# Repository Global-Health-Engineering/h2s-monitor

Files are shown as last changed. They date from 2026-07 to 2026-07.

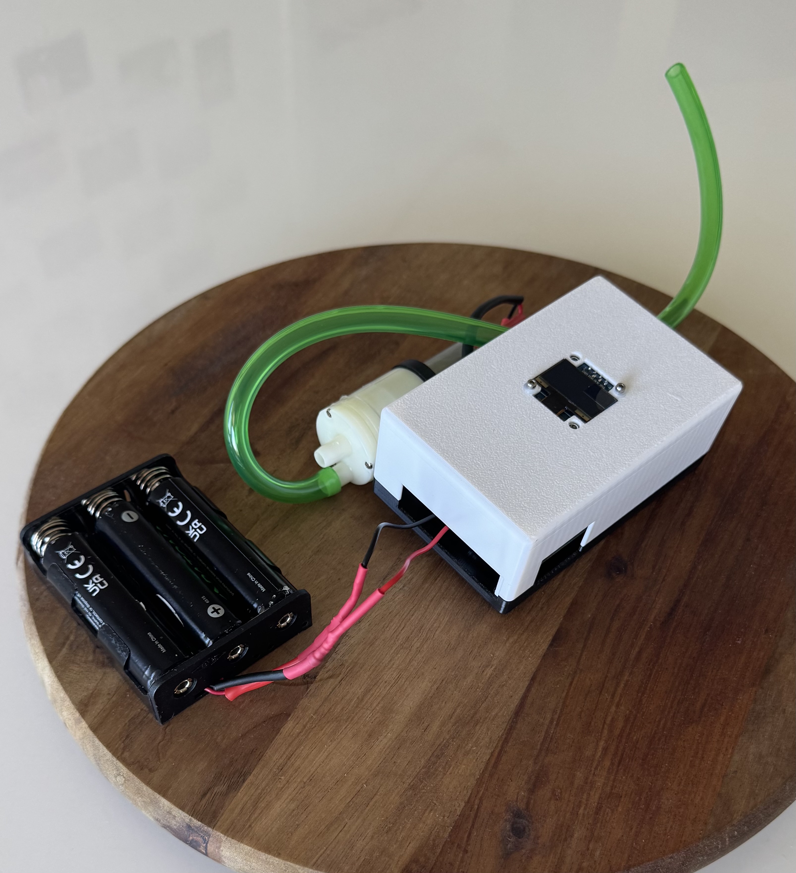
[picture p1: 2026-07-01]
media/photo/device_closed.jpeg

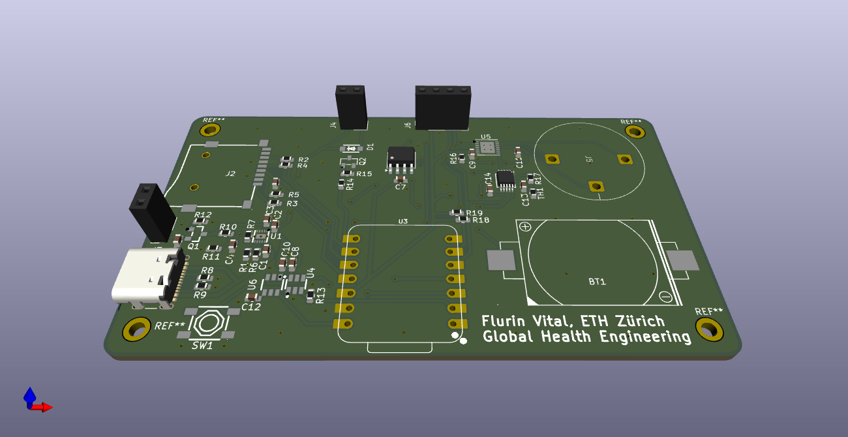
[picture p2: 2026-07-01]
media/photo/PCB_3D.png

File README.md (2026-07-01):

# H2S Monitor

Design and Development of a Low-Cost Hydrogen Sulfide Sensor System for Biogas Monitoring

**Author:** Flurin Vital
**Supervisors:** Prof. Dr. Elizabeth Tilley, Dr. Jakub Tkaczuk
**Institution:** ETH Zürich, Global Health Engineering (GHE)
**Date:** June 2026

## Overview

This project develops a low-cost, field-deployable hydrogen sulfide (H2S) sensor system for monitoring biogas quality. Biogas systems in low-resource settings frequently lack affordable tools for measuring H2S — a toxic and corrosive gas produced during anaerobic digestion that causes equipment degradation and safety hazards. Commercial H2S meters capable of covering the relevant concentration range (0–2000 ppm) cost upwards of CHF 4000 and are unsuitable for continuous field deployment.

The developed system integrates a three-electrode electrochemical H2S sensor into a single compact battery-powered device with a custom PCB, 3D-printed enclosure and gas flow chamber, and C++ firmware running on FreeRTOS. Total component cost is CHF 193.80 — approximately 95% cheaper than the commercial reference instrument (Dräger X-am 8000).

## System Components

| Component | Part |
|---|---|
| Microcontroller | Seeed XIAO ESP32-C6 |
| H2S Sensor | SUCH electrochemical, 0–2000 ppm, 85 ± 25 nA/ppm |
| Analog Front End | Texas Instruments LMP91002 |
| ADC | Texas Instruments ADS1115 (16-bit) |
| Display | 0.96" OLED, SSD1306 driver |
| RTC | Maxim DS3232M |
| Power Management | Texas Instruments BQ25185 |
| Storage | MicroSD card (SPI) |
| Gas Pump | DC micro diaphragm pump, 1.2 L/min |
| PCB | KiCad design, manufactured by JLCPCB |
| Enclosure | 3D-printed PLA (case) + resin (flow chamber) |

## Repository Structure

```
├── analysis/
├── data/
├── docs/
├── grading/
├── hardware/
├── media/
└── src/
```

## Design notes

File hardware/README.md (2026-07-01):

# Hardware

All hardware design files for the H2S sensor system, including the custom PCB and the 3D-printed enclosure and gas flow chamber.

## Structure

```
hardware/
├── design/
└── testing/
```

## System Overview

The hardware consists of three main physical components:

**Custom PCB** — designed in KiCad and manufactured by JLCPCB. Integrates the Seeed XIAO ESP32-C6 microcontroller, TI LMP91002 electrochemical analog front end, TI ADS1115 16-bit ADC, DS3232M RTC, SSD1306 OLED display, TI BQ25185 power management IC (USB-C charging, battery protection), MicroSD card slot, and N-channel MOSFET pump driver.

**3D-printed enclosure** — two-part PLA shell (bottom houses PCB, top carries display). Openings provide access to USB-C port, power button, MicroSD slot, and tube connectors.

**3D-printed flow chamber** — cylindrical chamber that seals around the electrochemical sensor body via an O-ring. A small internal cavity between the sensor face and the chamber top is flushed continuously by the diaphragm pump. Must be printed in resin for a gas-tight seal in field deployment; PLA is acceptable for bench testing only.

## Known Issues

- PCB revision V5 has a routing error on two of the four SPI lines to the MicroSD card, causing a short circuit that prevents SD card communication. SD logging is non-functional until corrected in the next revision.

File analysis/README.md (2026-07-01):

# Analysis

Python scripts for processing and analysing H2S sensor measurement data.

## Scripts

### `baseline.py`

Analyses the baseline stability of the sensor in clean ambient air. Reads a CSV file from `data/raw_data/baseline_stability/`, computes summary statistics (mean, standard deviation, peak-to-peak noise, linear drift slope), and generates a time series plot with a rolling mean and linear trend overlay.

**Input:** `data/raw_data/baseline_stability/h2s_20260601_115100.csv`
**Output:** summary statistics printed to console, timeseries plot

**Usage:**
```bash
python analysis/baseline.py
```

**Dependencies:** pandas, matplotlib, numpy

## Results Summary

Baseline stability test conducted over one hour in clean ambient air at ~27°C with the diaphragm pump running at nominal voltage:

| Metric | Value |
|---|---|
| Mean output | 0.33 ppm |
| Standard deviation | 0.51 ppm |
| Peak-to-peak noise | 3.65 ppm |
| Linear drift slope | 0.271 ppm/h |

Peak-to-peak noise of 3.65 ppm is well below the 10 ppm detection threshold defined as the minimum relevant concentration for biogas monitoring.

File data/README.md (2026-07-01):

# Data

This directory contains all measurement data collected during development and testing of the H2S sensor system.

## Structure

```
data/
├── raw_data/
├── derived_data/
└── metadata/
```

## Data Format

Raw data is logged by the firmware as CSV files at a 3-second sampling interval. Each row contains one sensor reading. Due to a PCB routing error affecting the MicroSD SPI lines in the current hardware revision, data was recorded via a serial connection to a computer using a capture script (`src/firmware/tools/capture_serial.py`) rather than directly to the SD card.

## Variables

| Column | Unit | Description |
|---|---|---|
| timestamp | YYYY-MM-DD HH:MM:SS | Wall-clock time from DS3232M RTC |
| h2s_ppm | ppm | H2S concentration computed from sensor current |
| temperature | °C | On-board temperature from thermistor |
| battery_v | V | Battery voltage from resistor divider on ADS1115 |

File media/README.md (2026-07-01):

# Media

Photos and videos of the assembled H2S sensor device and its components.

## Structure

```
media/
├── photo/
└── video/
```

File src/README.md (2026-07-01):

# Source Code

Firmware and software developed for the H2S sensor system.

## Structure

```
src/
└── firmware/
```

## `firmware/`

Written in C++, targeting the ESP-IDF framework (v6.0.0) with FreeRTOS, compiled via PlatformIO.

### Architecture

The application runs four concurrent FreeRTOS tasks:

| Task | Cycle | Responsibility |
|---|---|---|
| `SensorTask` | 3 s | Reads LMP91002 output via ADS1115, computes H2S concentration, pushes to queues |
| `DisplayTask` | 1 s | Refreshes OLED with concentration, time, temperature, battery status |
| `StorageTask` | — | Appends each sample as a CSV row to MicroSD card |
| `PowerTask` | — | Monitors battery voltage, handles controlled shutdown sequence |

Inter-task communication uses two FreeRTOS queues (`q_display`, `q_storage`). The shared I2C bus and SD filesystem are each protected by a mutex.

### Sensor Conversion

The LMP91002 is configured with a 35 kΩ transimpedance resistor and internal reference at 20% Vcc (Vref = 0.66 V). H2S concentration is computed as:

```
I_nA  = (Vcell - Vzero) / 35000 × 1e9
c_ppm = I_nA / 85
```

On each boot, the firmware discards 5 warm-up readings then averages 10 readings in clean air to compute `Vzero`, stored in non-volatile memory.

### Building and Flashing

Requires [PlatformIO](https://platformio.org/) with the `seeed_xiao_esp32c6` board target.

```bash
cd src/firmware
pio run --target upload
```

### Serial Data Capture

Due to a MicroSD routing error in the current PCB revision, data can be captured via USB serial using:

```bash
python src/firmware/tools/capture_serial.py
```

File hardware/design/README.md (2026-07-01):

# Design

PCB schematic and layout files, and CAD models for the enclosure and gas flow chamber.

## Structure

```
design/
├── pcb/
└── case_CAD/
```

## PCB (`pcb/`)

Designed in KiCad. The schematic is organised into functional blocks:
- **Power management** — TI BQ25185 (USB-C charging, single-cell LiPo, power path)
- **Microcontroller** — Seeed XIAO ESP32-C6
- **Analog front end & ADC** — TI LMP91002 + TI ADS1115 for electrochemical sensor signal conditioning
- **Peripherals** — DS3232M RTC, SSD1306 OLED, MicroSD (SPI), pump MOSFET driver

Production files in `pcb/production/` and `pcb/jlcpcb/` were submitted to JLCPCB for fabrication and assembly. `pcb/PCB_Versions/` contains archived snapshots of earlier design iterations (V1–V5).

The electrochemical sensor uses a custom KiCad footprint with press-fit through-hole pads — the sensor cannot withstand soldering temperatures and must not be soldered.

## CAD (`case_CAD/`)

Designed in OnShape, exported as STL for 3D printing.

| File | Material | Notes |
|---|---|---|
| `Case/Final/Case_Bottom.stl` | PLA | Houses PCB |
| `Case/Final/Case_Top.stl` | PLA | Carries OLED display |
| `Flow_Chamber/Flow_Chamber_final.stl` | Resin (field) / PLA (bench test) | Seals around sensor body with O-ring |

`Case/V1`–`V5` and `Flow_Chamber/V1`–`V5` contain earlier design iterations.

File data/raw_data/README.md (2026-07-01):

# Raw Data

Unprocessed sensor output as logged directly during measurements. Files are not modified after collection.

## Structure

```
raw_data/
└── baseline_stability/     # 1-hour baseline test in clean ambient air
```

## Datasets

### `baseline_stability/`

Continuous H2S sensor recording in clean ambient air with no H2S present. Used to characterise sensor noise, baseline offset, and drift.

| Parameter | Value |
|---|---|
| Duration | 1 hour |
| Sampling interval | 3 seconds |
| Ambient temperature | ~27°C |
| Pump state | Running at nominal voltage (3.7 V) |
| Logging method | Serial capture via `src/firmware/tools/capture_serial.py` |

**File naming convention:** `h2s_YYYYMMDD_HHMMSS.csv` (date and time of recording start)

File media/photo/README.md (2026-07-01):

# Photos

Still images of the assembled device, PCB, and design files.

## Files

| File | Description |
|---|---|
| `device_closed.jpeg` | Assembled device in closed configuration |
| `device_open.jpeg` | Device in open configuration showing PCB, flow chamber, pump, and battery |
| `PCB.png` | 3D rendering of the placed and routed PCB |
| `PCB_3D.png` | 3D rendering of the PCB from KiCad |
| `Schematic.pdf` | Full PCB schematic exported from KiCad |
| `CAD_design.png` | 3D rendering of the enclosure and flow chamber (case bottom, top shell, flow chamber) |

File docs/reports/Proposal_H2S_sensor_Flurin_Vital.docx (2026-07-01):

Design and Development of a Low-Cost Hydrogen Sulfide Sensor System for Biogas Monitoring

Flurin Vital

# Background

The global demand for renewable energy has grown substantially in recent decades, driven by the need to reduce dependence on fossil fuels and mitigate climate change. Biogas, produced through the anaerobic digestion of organic waste materials such as agricultural residues, municipal solid waste, and sewage sludge, has emerged as one of the most promising and versatile renewable energy carriers. It can be used directly for cooking and heating, converted to electricity, or upgraded to biomethane for injection into gas grids or use as vehicle fuel. The technology is applicable across a wide range of scales, from household digesters to large industrial plants, and has seen rapid growth in installed capacity across Europe, Asia, and increasingly Africa and Latin America (Navarro, 2025; Weiland, 2010).

While biogas technology is well established in Europe, its potential in the Global South is particularly significant. In Sub-Saharan Africa, South Asia, and Latin America, millions of households and smallholder farms generate large quantities of organic waste with limited access to modern energy services. Biogas represents a uniquely appropriate technology for these contexts because it simultaneously addresses energy poverty, waste management, and agricultural productivity through the nutrient-rich digestate it produces. However, persistent barriers to widespread adoption remain, including lack of technical capacity, limited access to spare parts, and the absence of affordable monitoring and quality control tools (Surendra et al., 2014). Projects in the Global South frequently underperform or fail not due to a lack of demand but due to inadequate operational support and monitoring infrastructure (Somorin et al., 2025). Africa's biogas sector has repeatedly attracted investment and optimism without delivering sustained impact at scale, partly because the operational realities of maintaining digesters in low-resource settings are systematically underestimated (Kalina et al., 2022). Long-term plant performance is rarely monitored, and gas quality in particular receives almost no systematic attention at the field level (Clemens et al., 2018).

A critical but frequently overlooked aspect of biogas quality is the presence of hydrogen sulfide (H₂S). H₂S is produced during anaerobic digestion whenever sulfur-containing organic compounds are broken down by sulfate-reducing bacteria. Its concentration in raw biogas varies considerably depending on feedstock composition, with typical ranges from below 100 ppm in some agricultural systems to several thousand ppm in biogas derived from sewage sludge or high-sulfur industrial waste (Ryckebosch et al., 2011). This variability makes continuous monitoring important, as concentrations can shift significantly with changes in feedstock or digester operation. Even at relatively low concentrations, H₂S is highly corrosive to metal components including engines, compressors, and piping, leading to accelerated wear and costly maintenance. At higher concentrations it also poses a serious acute health risk, with effects on the central nervous system and respiratory function documented at concentrations well below the levels commonly found in raw biogas (Lim et al., 2016). The WHO classifies H₂S as acutely toxic, with concentrations above 100 ppm posing an immediate danger to health (Chou & International Programme on Chemical Safety, 2003).

Despite the well-documented risks of H₂S in biogas systems, affordable and field-suitable monitoring solutions remain scarce. Commercially available portable H₂S meters are predominantly designed for occupational safety applications, where the relevant range is below 100 ppm, making them inadequate for biogas environments where concentrations routinely exceed this threshold. Laboratory-grade analyzers capable of covering higher concentration ranges are expensive, require calibration infrastructure, and are not suited to continuous deployment in remote or low-resource field settings. Electrochemical sensors represent the most promising platform for low-cost, portable H₂S detection, offering low power consumption, a compact form factor, and sufficient sensitivity for environmental and industrial monitoring applications (Pandey et al., 2012). The convergence of affordable electrochemical sensor technology, low-cost PCB fabrication services, and accessible microcontroller platforms creates a realistic opportunity to address the lack of affordable, field-deployable H₂S monitoring tools for biogas applications.

# Problem statement and goals

Hydrogen sulfide is a toxic and corrosive gas present in raw biogas at concentrations that frequently exceed 100 ppm, which is the upper limit of most commercially available portable meters. This monitoring gap poses both a safety risk to operators and an operational challenge for biogas plant management, particularly in low-resource settings where laboratory-grade equipment is not accessible. The goal of this project is to design and build a low-cost H₂S sensor system capable of detecting concentrations up to 1500 ppm. The system will consist of a digital electrochemical sensor, a miniature gas pump with a 3D-printed flow chamber, and a custom PCB with a display and data logging capability, assembled into a single compact device. Success is defined by the system functioning as an integrated unit, delivering adequate gas flow to the sensor, maintaining a stable output in clean air, and being realized at a component cost significantly below that of commercially available instruments.

# Research Questions

1. How can the sensor, microcontroller, display, and data logging components be integrated into a single compact and functional monitoring device?
2. What pump and flow chamber design is sufficient to deliver a gas sample to the sensor within a practically acceptable response time?
3. What baseline stability and noise levels does the signal conditioning circuit achieve in clean air, and are they sufficient for H₂S detection?
4. How does the component cost of the complete system compare to commercially available H₂S meters, and what cost reductions are achievable through design optimization or alternative component selection?

# Methods

1. A digital H₂S sensor will be selected based on datasheet specifications and availability, with the primary requirement being a direct digital concentration output covering the target measurement range. The sensor will be integrated with a microcontroller, a small display, and an SD card module on a custom PCB designed in KiCad. The PCB will be fabricated through JLCPCB and assembled into a single compact device, with the goal of producing a functional, self-contained monitoring unit.
2. A 3D-printed gas flow chamber will be designed in CAD to route sampled gas past the sensor element using a small off-the-shelf pump. The chamber geometry and pump flow rate will be selected based on the sensor manufacturer's recommended operating conditions. The adequacy of the design will be verified by measuring the actual flow rate delivered by the pump and comparing it against the datasheet specifications.
3. The assembled device will be powered continuously and the sensor output recorded in clean air over a period of time. Any noise and systematic drift in the digital output will be assessed over this period to establish whether the sensor provides a sufficiently stable baseline in the absence of H₂S.
4. A complete bill of materials will be documented throughout the development process, covering all electronic components, PCB fabrication costs, and 3D printing materials. The total system cost will be compared against the retail price of commercially available H₂S meters with equivalent or lower measurement ranges, and the main cost drivers will be identified.

# Planning

## Gantt chart

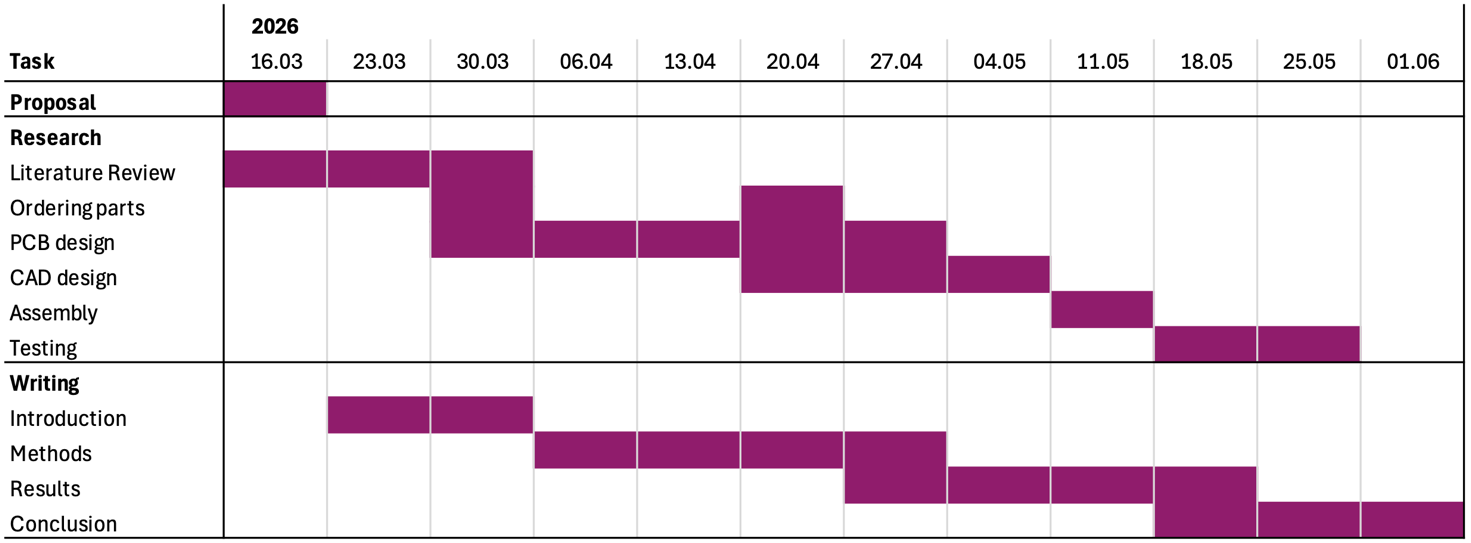
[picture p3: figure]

Figure 1. Gantt chart

The most important phases are the PCB design and the mechanical CAD design of the gas flow housing. These phases are the most critical as all subsequent testing and validation depends on functional hardware being available. The main potential bottleneck is component and PCB delivery time, as fabrication and shipping from services such as JLCPCB can take one to two weeks and any design errors requiring a second revision will cause significant delays. To mitigate this, to be purchased parts should be ordered as early as possible and PCB and housing designs should be finalized and orders placed no later than the midpoint of the project.

# Data Management Plan (DMP)

# Data collection

dataset | data type | data format | data documentation
PCB design | CAD data | KiCAD → Gerber (.gbr), Drill (.drl) | Version-controlled on GitHub
CAD design | 3D geometry | OnShape → STL file | Version-controlled on GitHub
Sensor measurements | Time-series data | CSV | Includes timestamp, concentration, raw signal
Change log | Text/ logs | Markdown/ text | GitHub commits and notes
(Secondary data) | Sensor datasheet

# Data storage

# All design files (KiCad, CAD) and experimental data will be stored in a version-controlled GitHub repository. Measurement data will be recorded in CSV format and analyzed using Python (NumPy, Pandas, Matplotlib). Backup copies will be maintained locally and on cloud storage.

# Budget

No | expense | amount | unit price [CHF] | total price [CHF] | link
1 | Hydrogen Sulfide Sensor | 1 | 189.- | 189.- | PSD4 (https://www.mouser.ch/ProductDetail/Amphenol-SGX-Sensortech/PSD4-H2S-5000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) PS4 (https://www.mouser.de/ProductDetail/Amphenol-SGX-Sensortech/PS4-H2S-5000?qs=vvQtp7zwQdMZZRZRVaAA7A%3D%3D)
2 | Microcontroller (Arduino) | 1 | 30.- | 30.- | nano (https://store.arduino.cc/products/arduino-nano?queryID=undefined)
3 | PCB | 1-2 | 30.- | 60.-
4 | Display | 1 | 15.- | 15.-
5 | SD card | 1
6 | Electro motor/ pump | 1 | ? | ? | pump (https://www.schwarzer.com/en/gas-pumps)
7 | Electronic Components | -
8 | 3D printing materials | -
| Total | | | 294.-

# References

Chou, C.-H. S. J. & International Programme on Chemical Safety (Hrsg.). (2003). Hydrogen sulfide: Human health aspects. World Health Organization.

Clemens, H., Bailis, R., Nyambane, A., & Ndung’u, V. (2018). Africa Biogas Partnership Program: A review of clean cooking implementation through market development in East Africa. Energy for Sustainable Development, Scaling Up Clean Fuel Cooking Programs, 46, 23–31. https://doi.org/10.1016/j.esd.2018.05.012

Kalina, M., Ogwang, J. Ò., & Tilley, E. (2022). From potential to practice: Rethinking Africa’s biogas revolution. Humanities and Social Sciences Communications, 9(1), 374. https://doi.org/10.1057/s41599-022-01396-x

Lim, E., Mbowe, O., Lee, A. S. W., & Davis, J. (2016). Effect of environmental exposure to hydrogen sulfide on central nervous system and respiratory function: A systematic review of human studies. International Journal of Occupational and Environmental Health, 22(1), 80–90. https://doi.org/10.1080/10773525.2016.1145881

Navarro, K. (2025, Oktober 16). World Biogas Association (WBA) | IEA Report Highlights Rapid Growth in the Global Biogas Industry. World Biogas Association (WBA). https://www.worldbiogasassociation.org/iea-report-highlights-rapid-growth-in-the-global-biogas-industry/

Pandey, S. K., Kim, K.-H., & Tang, K.-T. (2012). A review of sensor-based methods for monitoring hydrogen sulfide. TrAC Trends in Analytical Chemistry, 32, 87–99. https://doi.org/10.1016/j.trac.2011.08.008

Ryckebosch, E., Drouillon, M., & Vervaeren, H. (2011). Techniques for transformation of biogas to biomethane. Biomass and Bioenergy, 35(5), 1633–1645. https://doi.org/10.1016/j.biombioe.2011.02.033

Somorin, T., Bodach, S., & Tripathi, M. (2025). From waste to value: Key insights and lessons learned from biogas initiatives in the Global South. International Water Management Institute (IWMI). https://doi.org/10.5337/2025.202

Surendra, K. C., Takara, D., Hashimoto, A. G., & Khanal, S. K. (2014). Biogas as a sustainable energy source for developing countries: Opportunities and challenges. Renewable and Sustainable Energy Reviews, 31, 846–859. https://doi.org/10.1016/j.rser.2013.12.015

Weiland, P. (2010). Biogas production: Current state and perspectives. Applied Microbiology and Biotechnology, 85(4), 849–860. https://doi.org/10.1007/s00253-009-2246-7

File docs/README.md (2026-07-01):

# Docs

Project documents generated as part of the BSc thesis.

## Structure

```
docs/
├── reports/
└── slides/
```

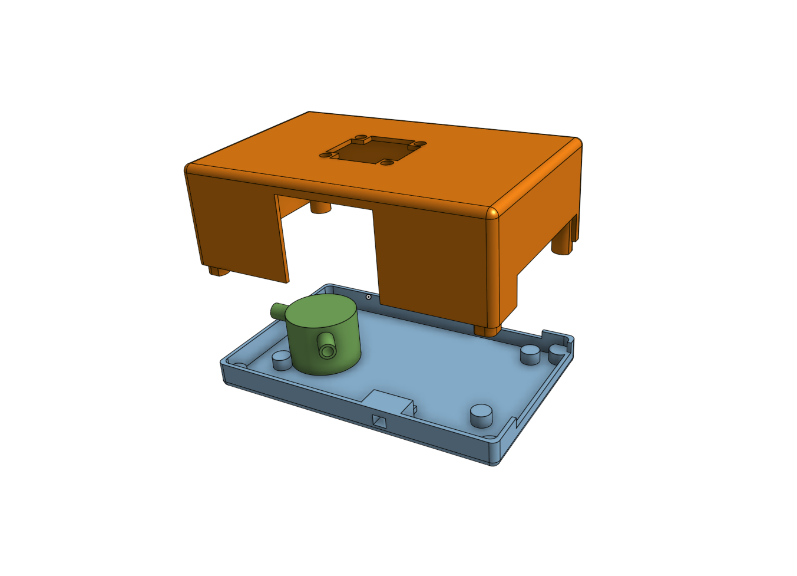
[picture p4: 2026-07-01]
media/photo/CAD_design.png

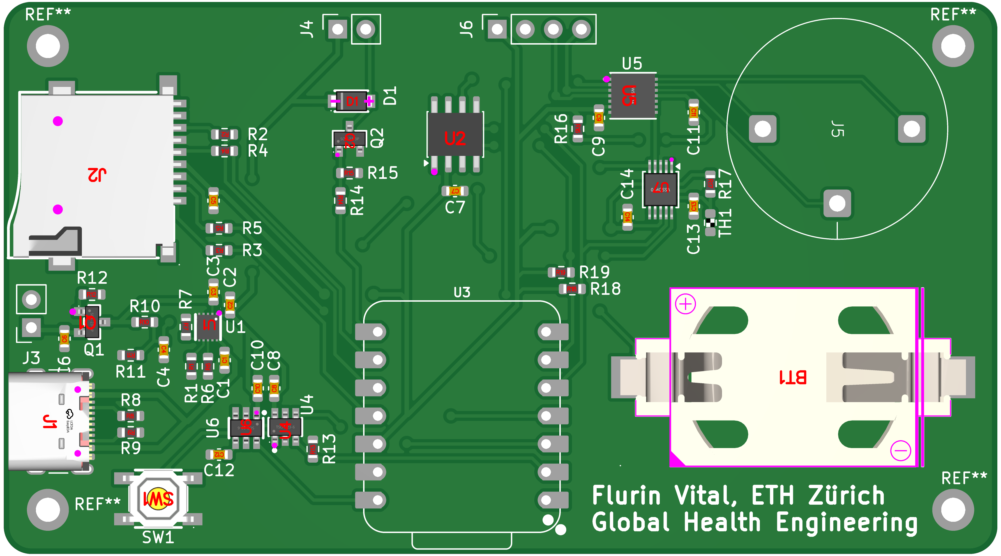
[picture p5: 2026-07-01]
media/photo/PCB.png

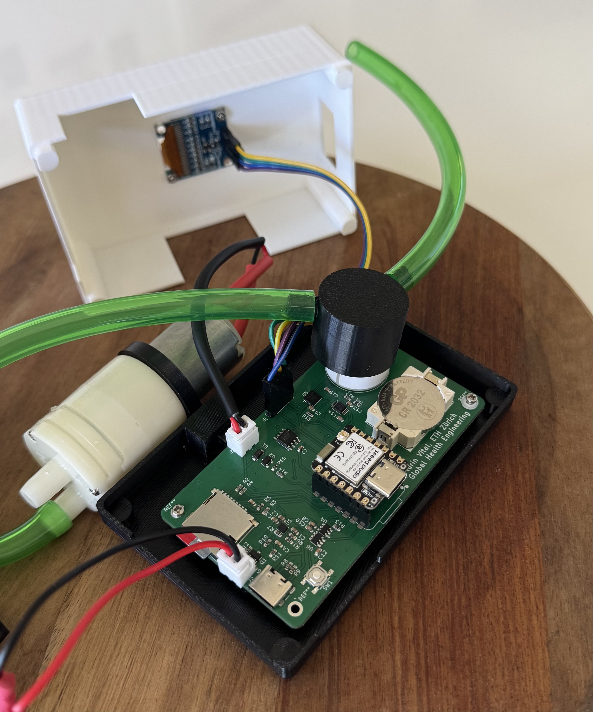
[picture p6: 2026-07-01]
media/photo/device_open.jpeg

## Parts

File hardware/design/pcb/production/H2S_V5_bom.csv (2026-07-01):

Designator | Footprint | Quantity | Value | LCSC Part #
BT1 | BAT-TH_CR2032-BS-6-1 | 1 | CR2032 | C70377
C1, C3 | 0603 | 2 | 1uF | C15849
C10, C11, C13, C14, C4, C5, C7, C8, C9 | 0603 | 9 | 100nF | C14663
C12 | 0603 | 1 | 10nF | C57112
C2, C6 | 0603 | 2 | 10uF | C96446
D1 | SOD-123F_L2.8-W1.8-LS3.7-RD | 1 | 1N5819W | C169540
J1 | USB_C_Receptacle_GCT_USB4105-xx-A_16P_TopMnt_Horizontal | 1 | USB_C_Receptacle_USB2.0_16P | C2927037
J2 | TF-SMD_TF-15-15 | 1 | SD_Card_Device | C111196
Q1 | SOT-23_L2.9-W1.3-P1.90-LS2.4-BR | 1 | AO3401A | C15127
Q2 | SOT-23-3_L2.9-W1.3-P1.90-LS2.4-BR | 1 | AO3400A | C20917
R1 | 0603 | 1 | 18kΩ | C25810
R10 | 0603 | 1 | 100kΩ | C22935
R11 | 0603 | 1 | 51kΩ | C23192
R12, R15, R7 | 0603 | 3 | 10kΩ | C25804
R13, R17 | 0603 | 2 | 10k | C25804
R14 | 0603 | 1 | 100Ω | C22775
R16 | 0603 | 1 | 10Ω | C22859
R18, R19 | 0603 | 2 | 4.7kΩ | C23162
R2, R3, R4, R5 | 0603 | 4 | 22Ω | C23345
R6 | 0603 | 1 | 1kΩ | C21190
R8, R9 | 0603 | 2 | 5.1k | C23186
SW1 | SW-SMD_4P-L5.2-W5.2-P3.70-LS6.5 | 1 | 4*4*1.7 | C10852
TH1 | 0603 | 1 | Thermistor_NTC | C7462093
U1 | WSON-10_L2.2-W2.0-P0.40-BL-EP_TI_DLH0010A | 1 | BQ25185DLHR | C19725033
U2 | SOIC-8_3.9x4.9mm_P1.27mm | 1 | DS3232M | C2651581
U4 | TSOT-23-6_L2.9-W1.6-P0.95-LS2.8-TL | 1 | MAX16054AZT+T | C79401
U5 | WSON-14_L4.0-W4.0-P0.50-BL-EP | 1 | LMP91002SDX/NOPB | C2651581
U6 | SOT-23-6_L2.9-W1.6-P0.95-LS2.8-BR | 1 | TPS22918TDBVRQ1 | C2653760
U7 | TSSOP-10_3x3mm_P0.5mm | 1 | ADS1115IDGS | C468683

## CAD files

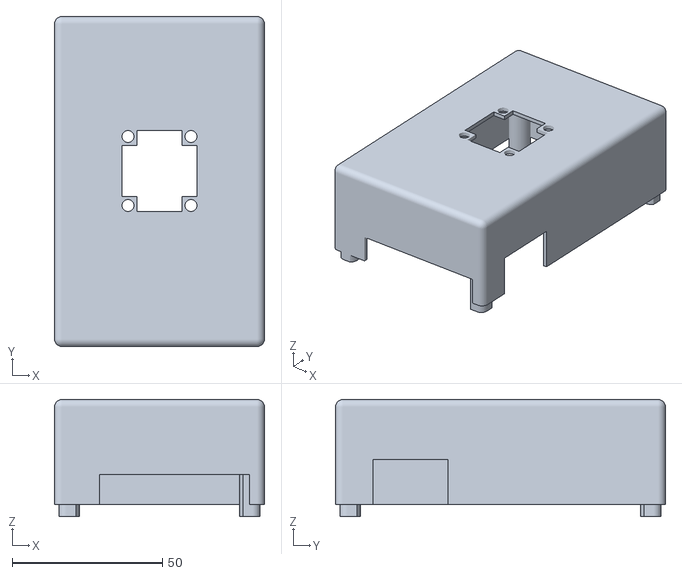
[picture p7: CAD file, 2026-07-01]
hardware/design/case_CAD/Case/Final/Case_Top - Part 1.stl
70.0 x 110.0 x 39.0

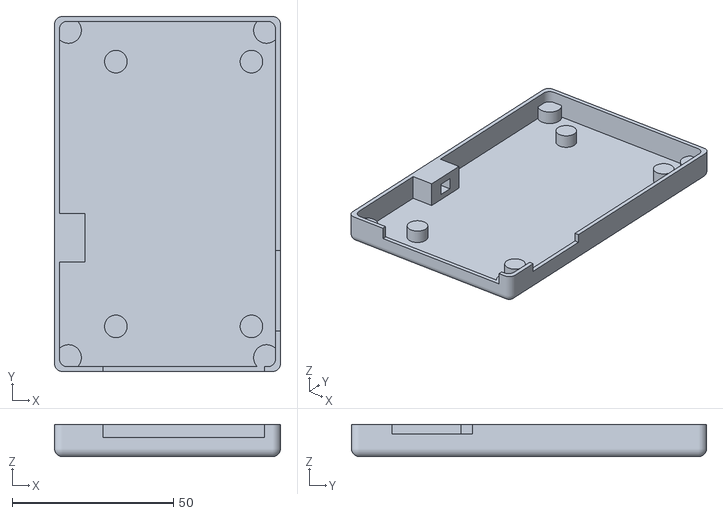
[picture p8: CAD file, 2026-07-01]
hardware/design/case_CAD/Case/Final/Case_Bottom - Part 1.stl
70.0 x 110.0 x 10.0

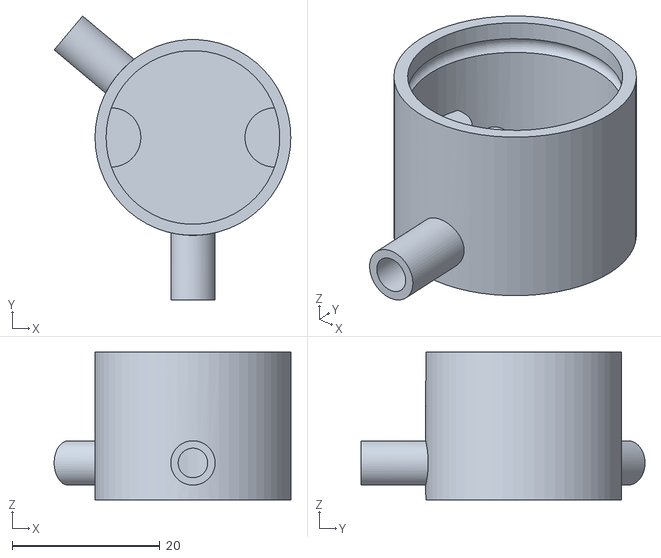
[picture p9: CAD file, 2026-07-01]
hardware/design/case_CAD/Flow_Chamber/Flow_Chamber - Part 1_final.stl
32.0 x 38.4 x 20.0

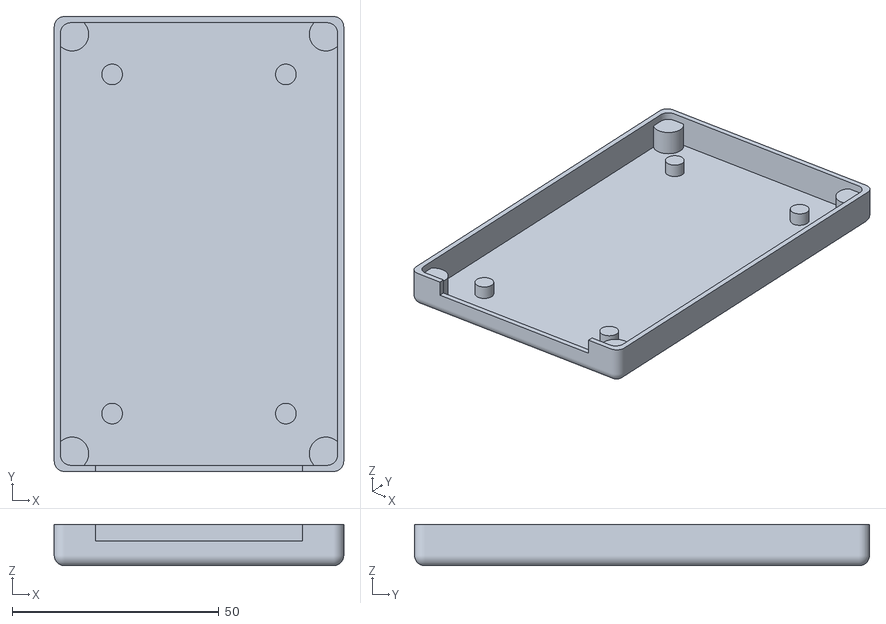
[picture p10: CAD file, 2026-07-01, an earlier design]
hardware/design/case_CAD/Case/V1/Case_Bottom - Part 1.stl
70.0 x 110.0 x 10.0

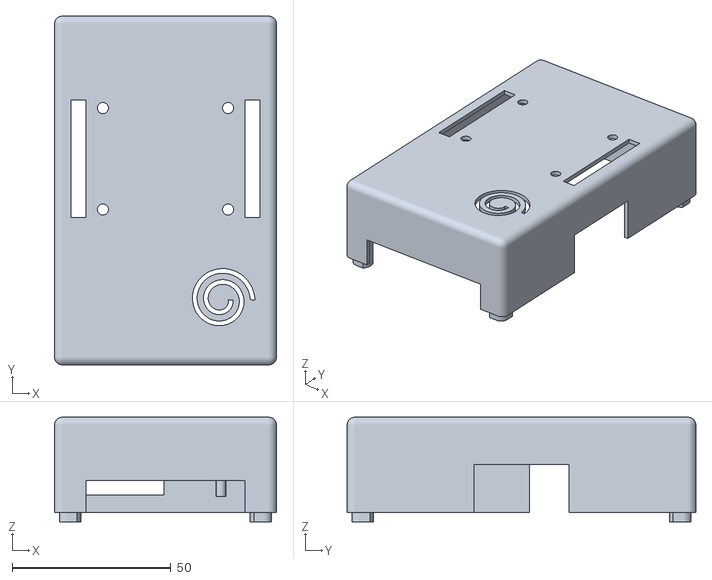
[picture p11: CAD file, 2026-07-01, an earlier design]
hardware/design/case_CAD/Case/V2/Case_Top - Part 1.stl
70.0 x 110.0 x 33.0

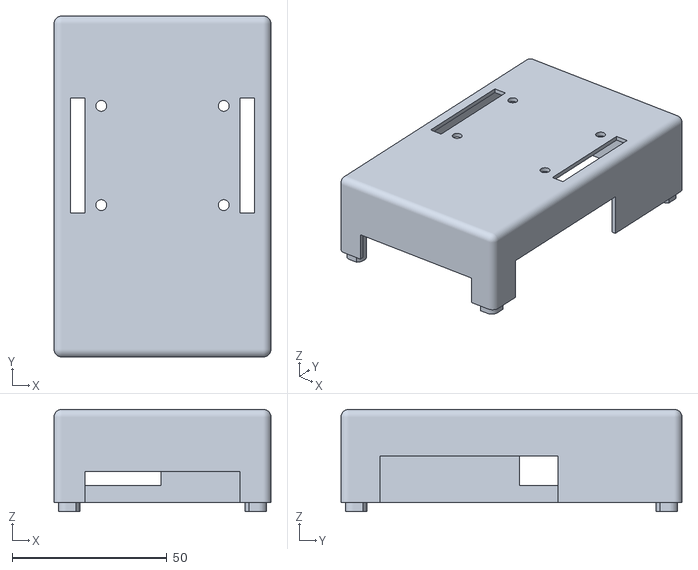
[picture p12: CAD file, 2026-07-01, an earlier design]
hardware/design/case_CAD/Case/V3/Case_Top - Part 1.stl
70.0 x 110.0 x 33.0

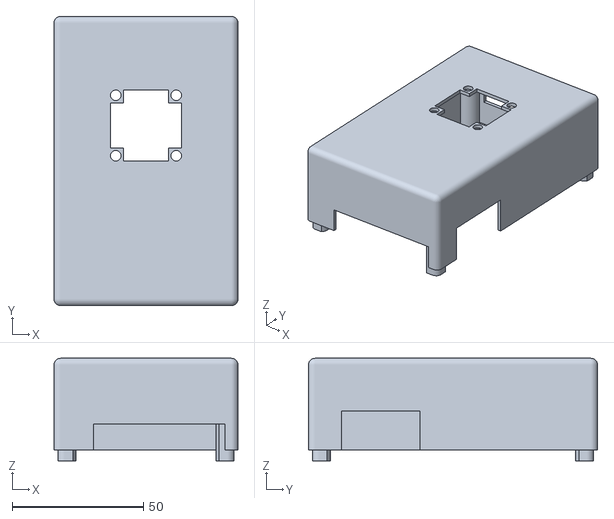
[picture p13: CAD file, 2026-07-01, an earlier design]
hardware/design/case_CAD/Case/V4/Case_Top - Part 1.stl
70.0 x 110.0 x 39.0

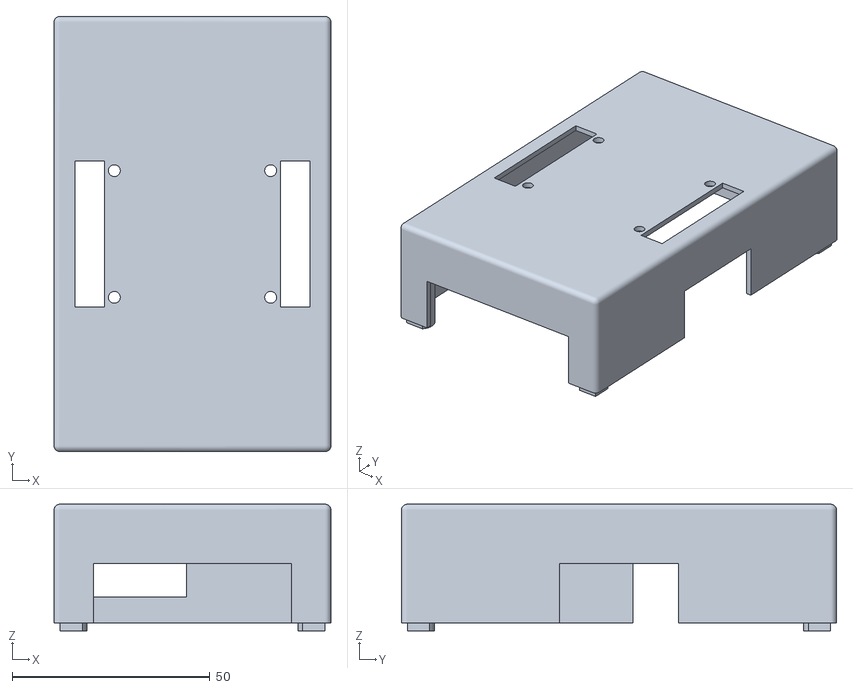
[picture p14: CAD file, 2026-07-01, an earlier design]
hardware/design/case_CAD/Case/V1/Case_Top - Part 1.stl
70.0 x 110.0 x 32.0

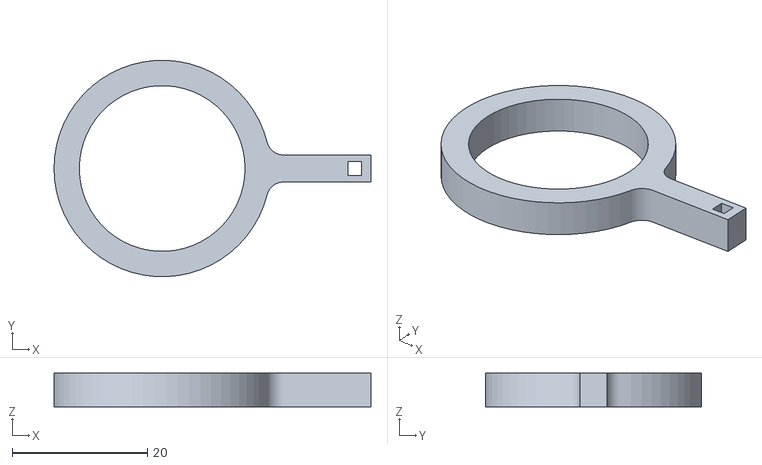
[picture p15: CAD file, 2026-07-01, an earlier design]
hardware/design/case_CAD/Case/V4/Pump_Mount - Part 1.stl
46.9 x 32.0 x 5.00

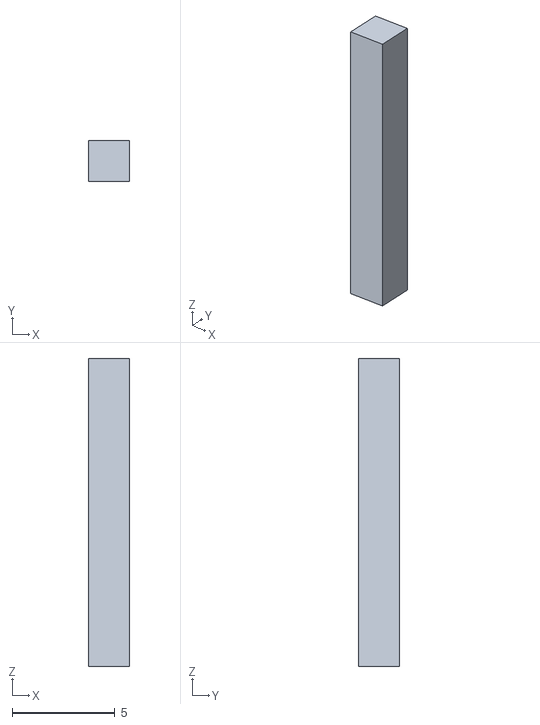
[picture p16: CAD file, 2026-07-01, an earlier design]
hardware/design/case_CAD/Case/V4/Pump_Lock - Part 1.stl
2.00 x 2.00 x 15.0

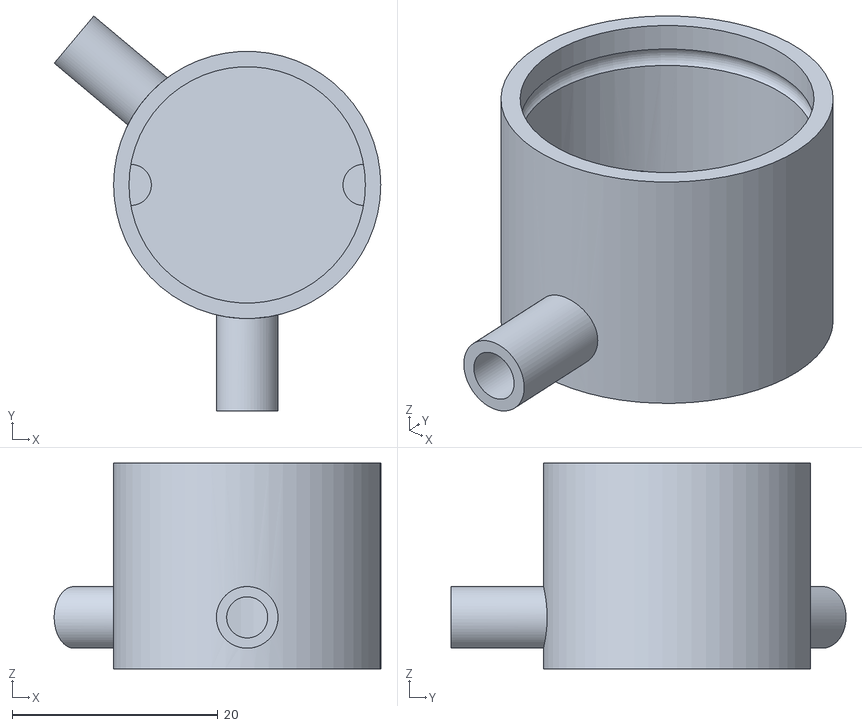
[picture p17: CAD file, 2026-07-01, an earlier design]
hardware/design/case_CAD/Flow_Chamber/Flow_Chamber - Part 1_V3.stl
31.8 x 38.4 x 20.0

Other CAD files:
hardware/design/case_CAD/Flow_Chamber/Flow_Chamber - Part 1_V2.stl
hardware/design/case_CAD/Case/V2/Case_Bottom - Part 1.stl
hardware/design/case_CAD/Case/V3/Case_Bottom - Part 1.stl
hardware/design/case_CAD/Flow_Chamber/Flow_Chamber - Part 1_V4.stl
hardware/design/case_CAD/Flow_Chamber/Flow_Chamber - Part 1_V1.stl

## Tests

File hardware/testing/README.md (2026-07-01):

# Testing

Hardware testing documentation for the H2S sensor system.

## Tests Performed

### Baseline Stability (June 2026)
Continuous 1-hour recording in clean ambient air with pump running. See `data/raw_data/baseline_stability/` for raw data and `analysis/baseline.py` for analysis. Peak-to-peak noise: 3.65 ppm (below 10 ppm threshold).

### Gas Flow Verification
Theoretical minimum flush time of the flow chamber cavity (17.3 mL) at rated pump flow (1.2 L/min): ~0.87 s. Actual flush time at 3.7 V operating voltage not independently measured. Attempt to validate with decomposing egg as H2S source was inconclusive — no detectable concentration registered on reference meter.

### System Integration
All I2C peripherals (LMP91002, ADS1115, DS3232M, SSD1306) initialise and communicate correctly. MicroSD SPI communication non-functional due to PCB routing error on two SPI lines (to be corrected in next revision).

## Pending Validation

- Sensor response to known H2S concentrations (requires calibration gas)
- SD card end-to-end logging after PCB routing fix
- Gas-tight seal verification with resin-printed flow chamber

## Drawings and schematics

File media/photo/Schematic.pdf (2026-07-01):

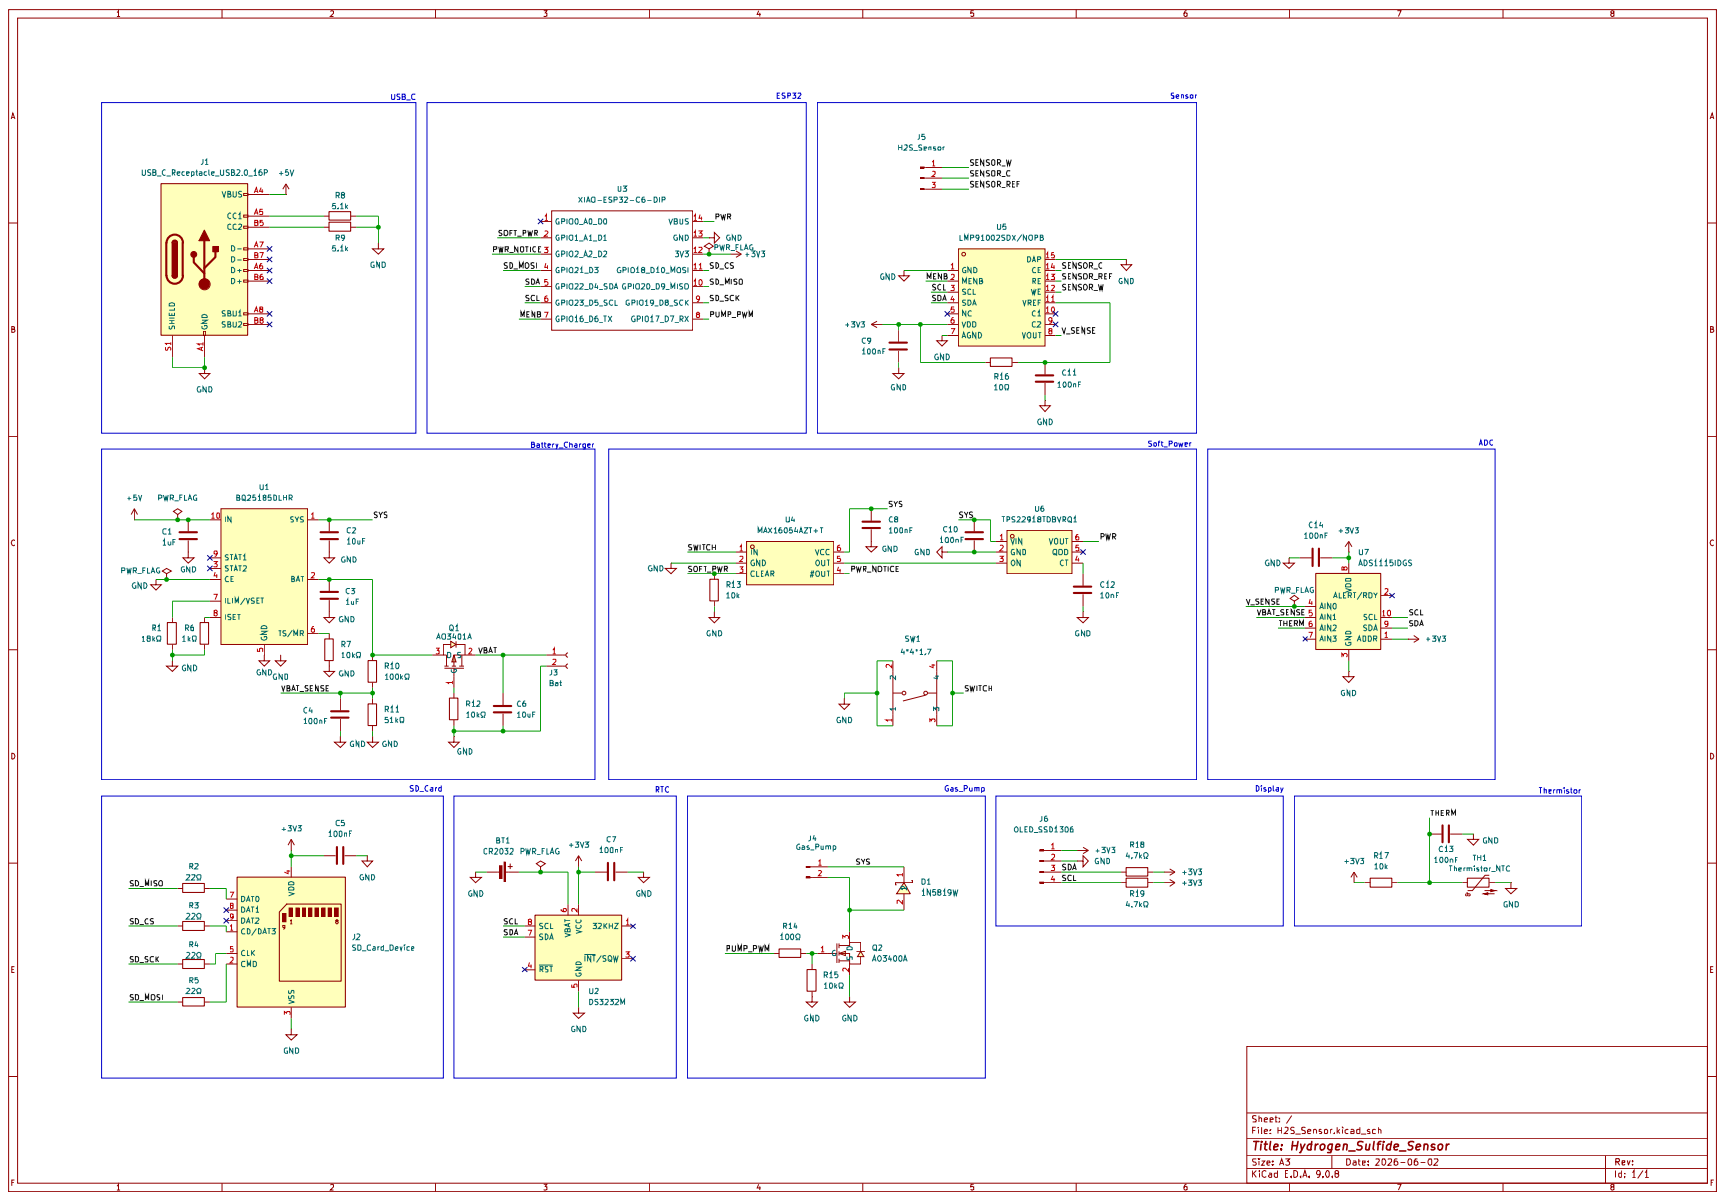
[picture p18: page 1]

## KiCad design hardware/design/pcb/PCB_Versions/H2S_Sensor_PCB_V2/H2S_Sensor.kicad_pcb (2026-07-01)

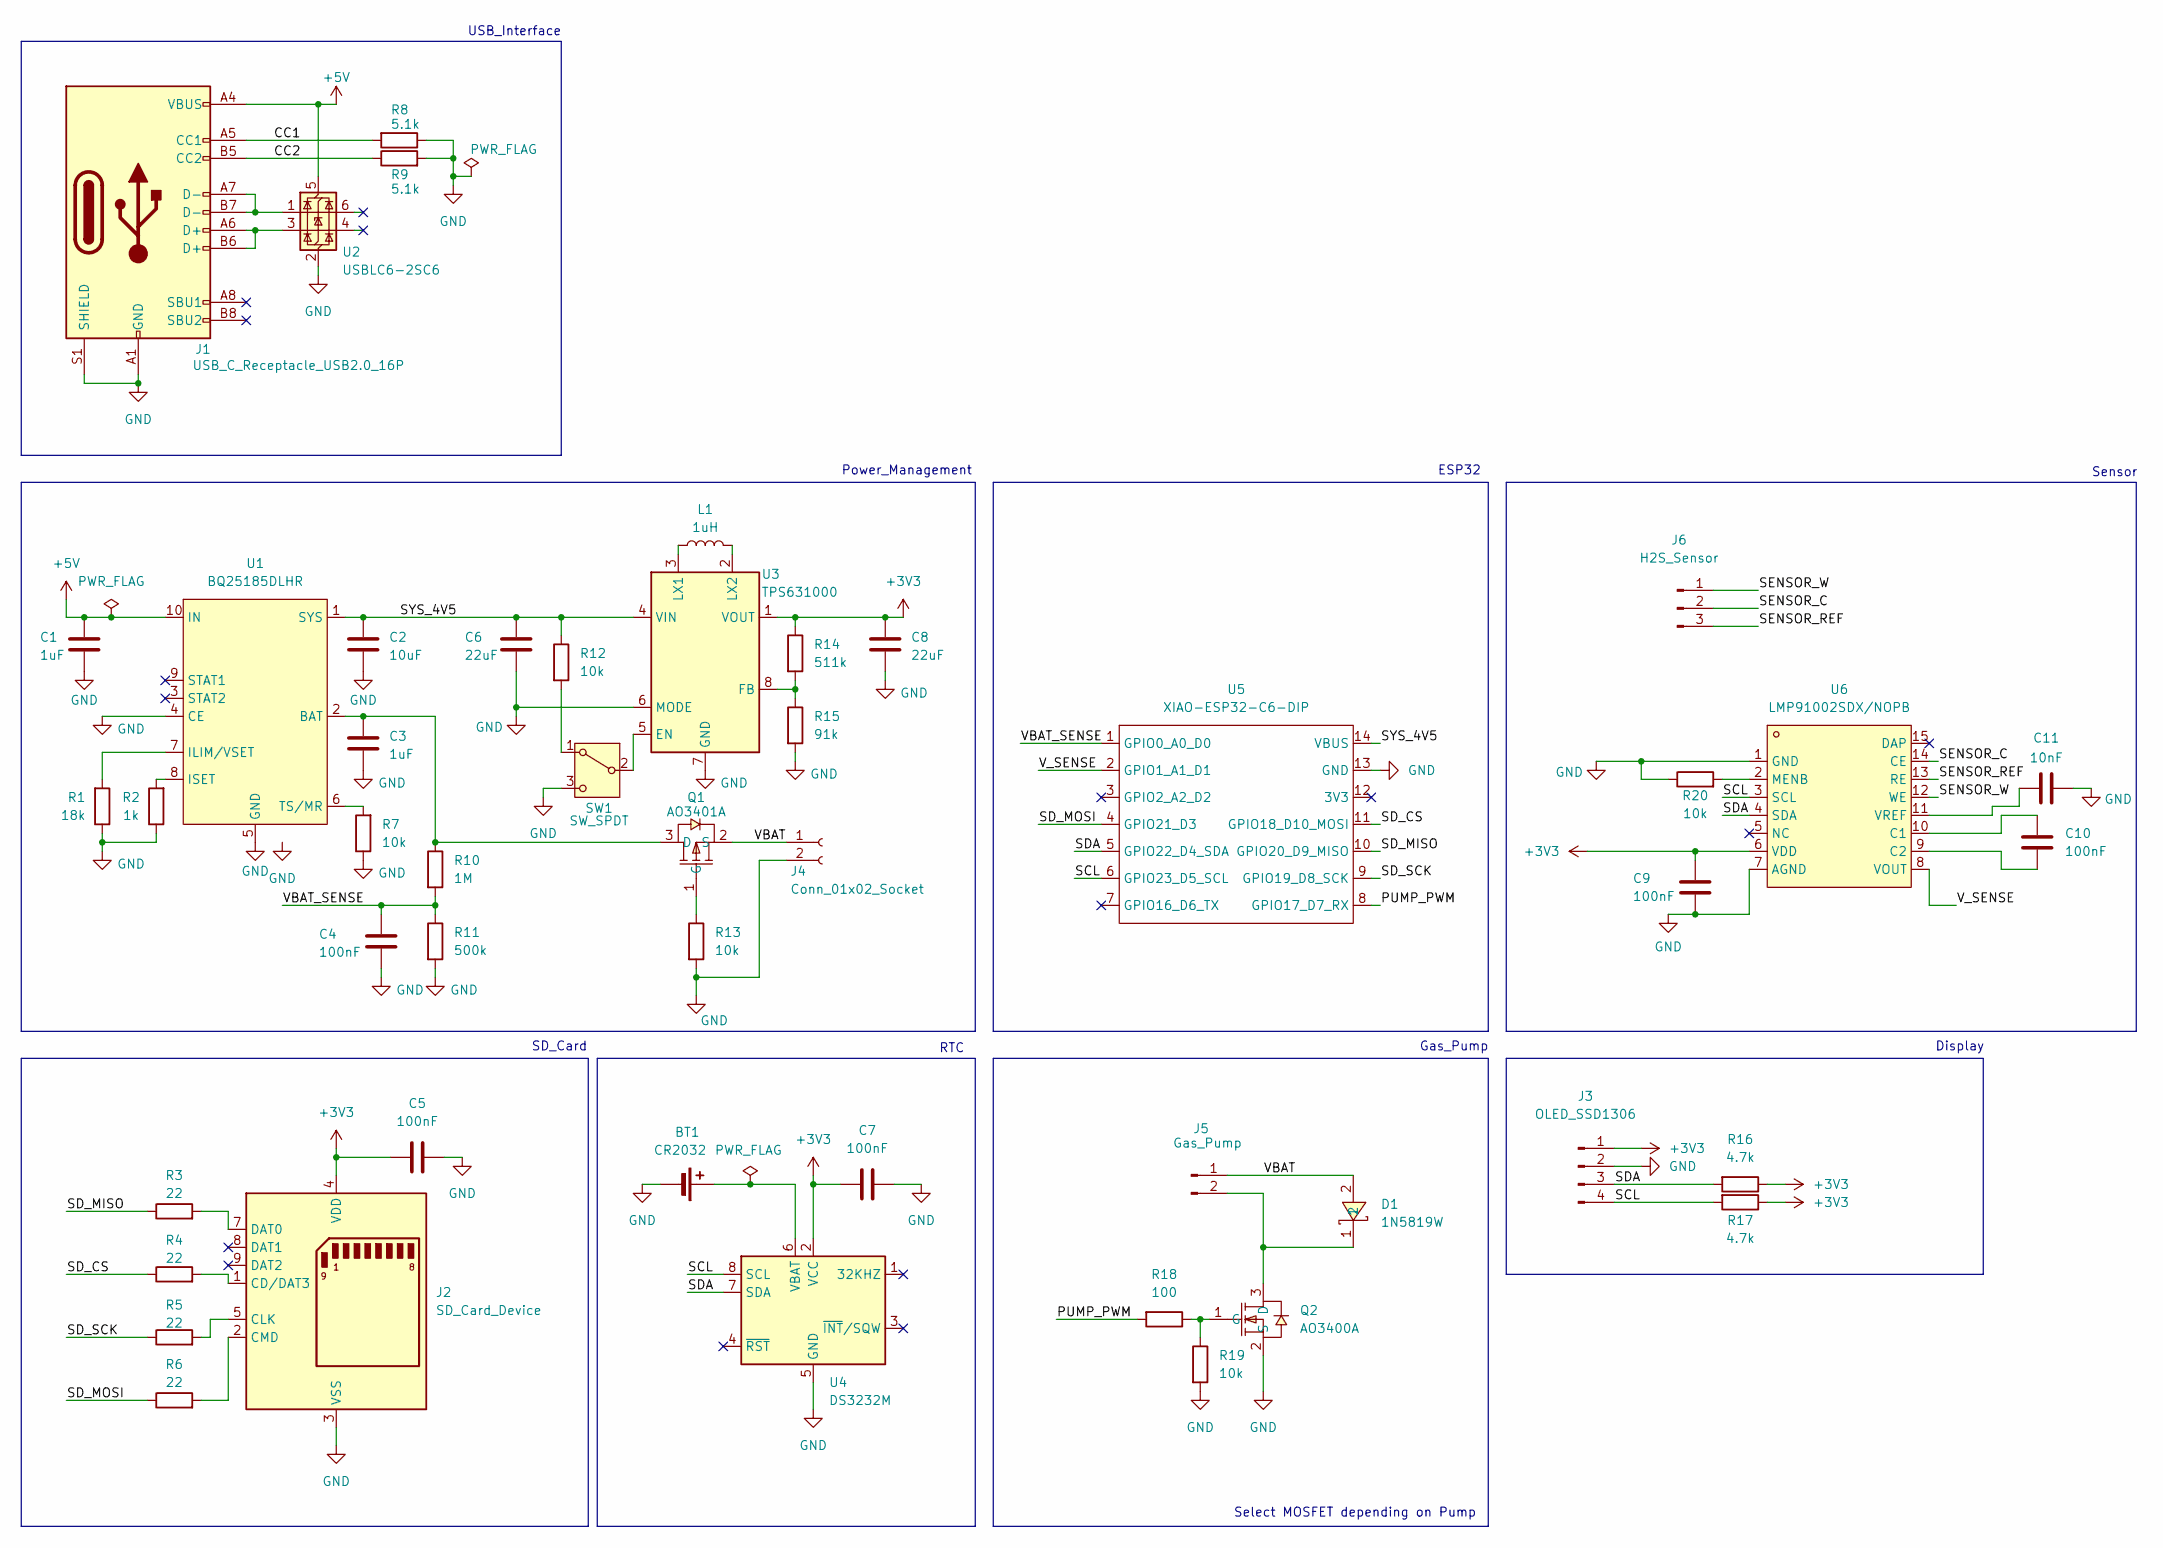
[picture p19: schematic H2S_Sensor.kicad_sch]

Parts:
BT1: CR2032; BAT-TH_CR2032-BS-6-1; LCSC Part C70377
C1, C3: 1uF; C_0603_1608Metric
C2: 10uF; C_0603_1608Metric
C4, C5, C7, C9, C10: 100nF; C_0603_1608Metric
C6, C8: 22uF; C_0603_1608Metric
C11: 10nF; C_0603_1608Metric
D1: 1N5819W; SOD-123F_L2.8-W1.8-LS3.7-RD; MPN 1N5819W; LCSC Part C169540
J1: USB_C_Receptacle_USB2.0_16P; USB_C_Receptacle_GCT_USB4105-xx-A_16P_TopMnt_Horizontal
J2: SD_Card_Device; SD-SMD_5045280892; LCSC Part C125620
J3: OLED_SSD1306; Hirose_DF13-04P-1.25DSA_1x04_P1.25mm_Vertical
J4: Conn_01x02_Socket; Hirose_DF13-02P-1.25DSA_1x02_P1.25mm_Vertical
J5: Gas_Pump; Hirose_DF13-02P-1.25DSA_1x02_P1.25mm_Vertical
J6: H2S_Sensor; H2S_Sensor_3Pin_D20mm
L1: 1uH; L_0805_2012Metric
Q1: AO3401A; SOT-23_L2.9-W1.3-P1.90-LS2.4-BR; MPN AO3401A; LCSC Part C15127
Q2: AO3400A; SOT-23-3_L2.9-W1.3-P1.90-LS2.4-BR; MPN AO3400A; LCSC Part C20917
R1: 18k; R_0603_1608Metric
R2: 1k; R_0603_1608Metric
R3, R4, R5, R6: 22; R_0603_1608Metric
R7, R12, R13, R19, R20: 10k; R_0603_1608Metric
R8, R9: 5.1k; R_0603_1608Metric
R10: 1M; R_0603_1608Metric
R11: 500k; R_0603_1608Metric
R14: 511k; R_0603_1608Metric
R15: 91k; R_0603_1608Metric
R16, R17: 4.7k; R_0603_1608Metric
R18: 100; R_0603_1608Metric
SW1: SW_SPDT; SW-SMD_MSK-03-HB; LCSC Part C54948
U1: BQ25185DLHR; WSON-10_L2.2-W2.0-P0.40-BL-EP_TI_DLH0010A; LCSC Part C19725033
U2: USBLC6-2SC6; SOT-23-6_L2.9-W1.6-P0.95-LS2.8-BL; LCSC Part C7519
U3: TPS631000; SOT-583-8_L2.1-W1.2-P0.50-LS1.6-BL; LCSC Part C5219190
U4: DS3232M; SOIC-8_3.9x4.9mm_P1.27mm
U5: XIAO-ESP32-C6-DIP
U6: LMP91002SDX/NOPB; WSON-14_L4.0-W4.0-P0.50-BL-EP; MPN LMP91002SDX/NOPB; LCSC Part C2651581

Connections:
+3V3: C5.1, C7.2, C8.2, C9.1, J2.4 (VDD), J3.1, R14.1, R16.1, R17.1, U3.1 (VOUT), U4.2 (VCC), U6.6 (VDD)
+5V: C1.2, J1.A4 (VBUS), J1.A9 (VBUS), J1.B4 (VBUS), J1.B9 (VBUS), U1.10 (IN), U2.5 (VBUS)
/CC1: J1.A5 (CC1), R8.2
/CC2: J1.B5 (CC2), R9.1
/PUMP_PWM: R18.2, U5.8 (GPIO17_D7_RX)
/SCL: J3.4, R17.2, U4.8 (SCL), U5.6 (GPIO23_D5_SCL), U6.3 (SCL)
/SDA: J3.3, R16.2, U4.7 (SDA), U5.5 (GPIO22_D4_SDA), U6.4 (SDA)
/SD_CS: R4.1, U5.11 (GPIO18_D10_MOSI)
/SD_MISO: R3.1, U5.10 (GPIO20_D9_MISO)
/SD_MOSI: R6.1, U5.4 (GPIO21_D3)
/SD_SCK: R5.1, U5.9 (GPIO19_D8_SCK)
/SENSOR_C: J6.2, U6.14 (CE)
/SENSOR_REF: J6.3, U6.13 (RE)
/SENSOR_W: J6.1, U6.12 (WE)
/SYS_4V5: C2.2, C6.2, R12.1, U1.1 (SYS), U3.4 (VIN), U5.14 (VBUS)
/VBAT: D1.2, J4.1, J5.1, Q1.2 (S)
/VBAT_SENSE: C4.1, R10.2, R11.1, U5.1 (GPIO0_A0_D0)
/V_SENSE: U5.2 (GPIO1_A1_D1), U6.8 (VOUT)
GND: BT1.2 (-), C1.1, C2.1, C3.1, C4.2, C5.2, C6.1, C7.1, C8.1, C9.2, C11.2, J1.A1 (GND), J1.A12 (GND), J1.B1 (GND), J1.B12 (GND), J1.S1 (SHIELD), J2.3 (VSS), J2.6 (VSS), J3.2, J4.2, Q2.2 (S), R1.1, R2.1, R7.1, R8.1, R9.2, R11.2, R13.2, R15.2, R19.2, R20.1, SW1.3 (C), U1.4 (CE), U1.5 (GND), U1.11 (VSS), U2.2 (GND), U3.6 (MODE), U3.7 (GND), U4.5 (GND), U5.13 (GND), U6.1 (GND), U6.7 (AGND), U6.15 (DAP)
unnamed: BT1.1 (+), U4.6 (VBAT)
unnamed: J1.A6 (D+), J1.B6 (D+), U2.3 (I/O2)
unnamed: J1.A7 (D-), J1.B7 (D-), U2.1 (I/O1)
unnamed: J2.1 (CD/DAT3), R4.2
unnamed: J2.5 (CLK), R5.2
unnamed: J2.2 (CMD), R6.2
unnamed: J2.7 (DAT0), R3.2
unnamed: D1.1, J5.2, Q2.3 (D)
unnamed: C3.2, Q1.3 (D), R10.1, U1.2 (BAT)
unnamed: Q1.1 (G), R13.1
unnamed: Q2.1 (G), R18.1, R19.1
unnamed: R12.2, SW1.1 (A)
unnamed: SW1.2 (B), U3.5 (EN)
unnamed: R1.2, U1.7 (ILIM/VSET)
unnamed: R2.2, U1.8 (ISET)
unnamed: R7.2, U1.6 (TS/MR)
unnamed: R14.2, R15.1, U3.8 (FB)
unnamed: L1.1, U3.3 (LX1)
unnamed: L1.2, U3.2 (LX2)
unnamed: C10.1, U6.10 (C1)
unnamed: C10.2, U6.9 (C2)
unnamed: R20.2, U6.2 (MENB)
unnamed: C11.1, U6.11 (VREF)

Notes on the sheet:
Gas_Pump
Sensor
USB_Interface
ESP32
Display
RTC
Select MOSFET depending on Pump
SD_Card
Power_Management

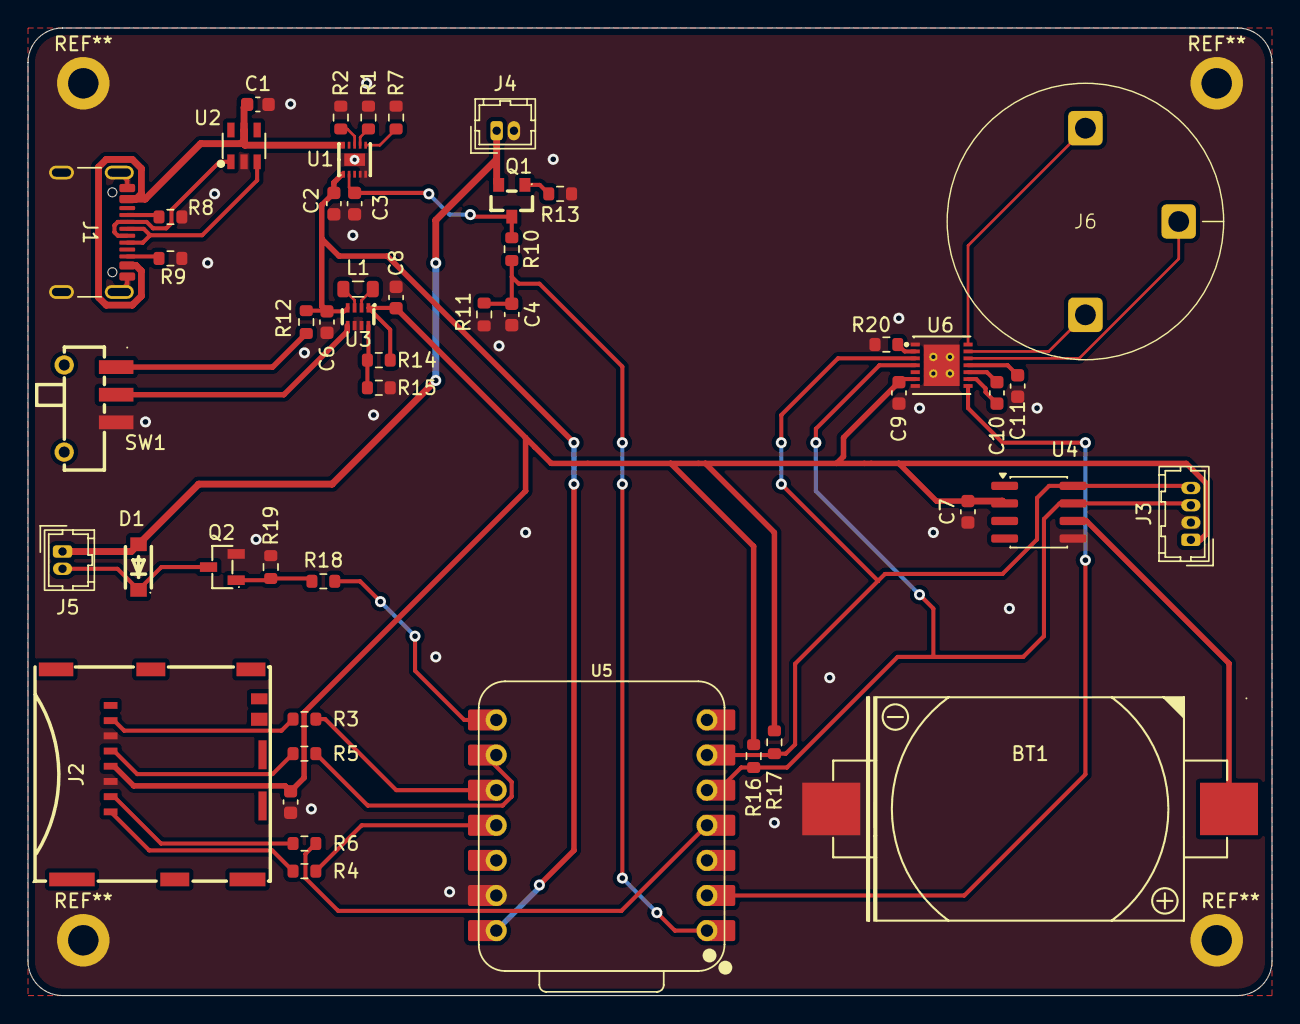
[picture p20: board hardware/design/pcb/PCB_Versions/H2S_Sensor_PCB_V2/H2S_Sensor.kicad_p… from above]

Board: 2 copper layers, 90.0 x 70.0 mm, 49 parts (0 on the bottom side), 42 nets.

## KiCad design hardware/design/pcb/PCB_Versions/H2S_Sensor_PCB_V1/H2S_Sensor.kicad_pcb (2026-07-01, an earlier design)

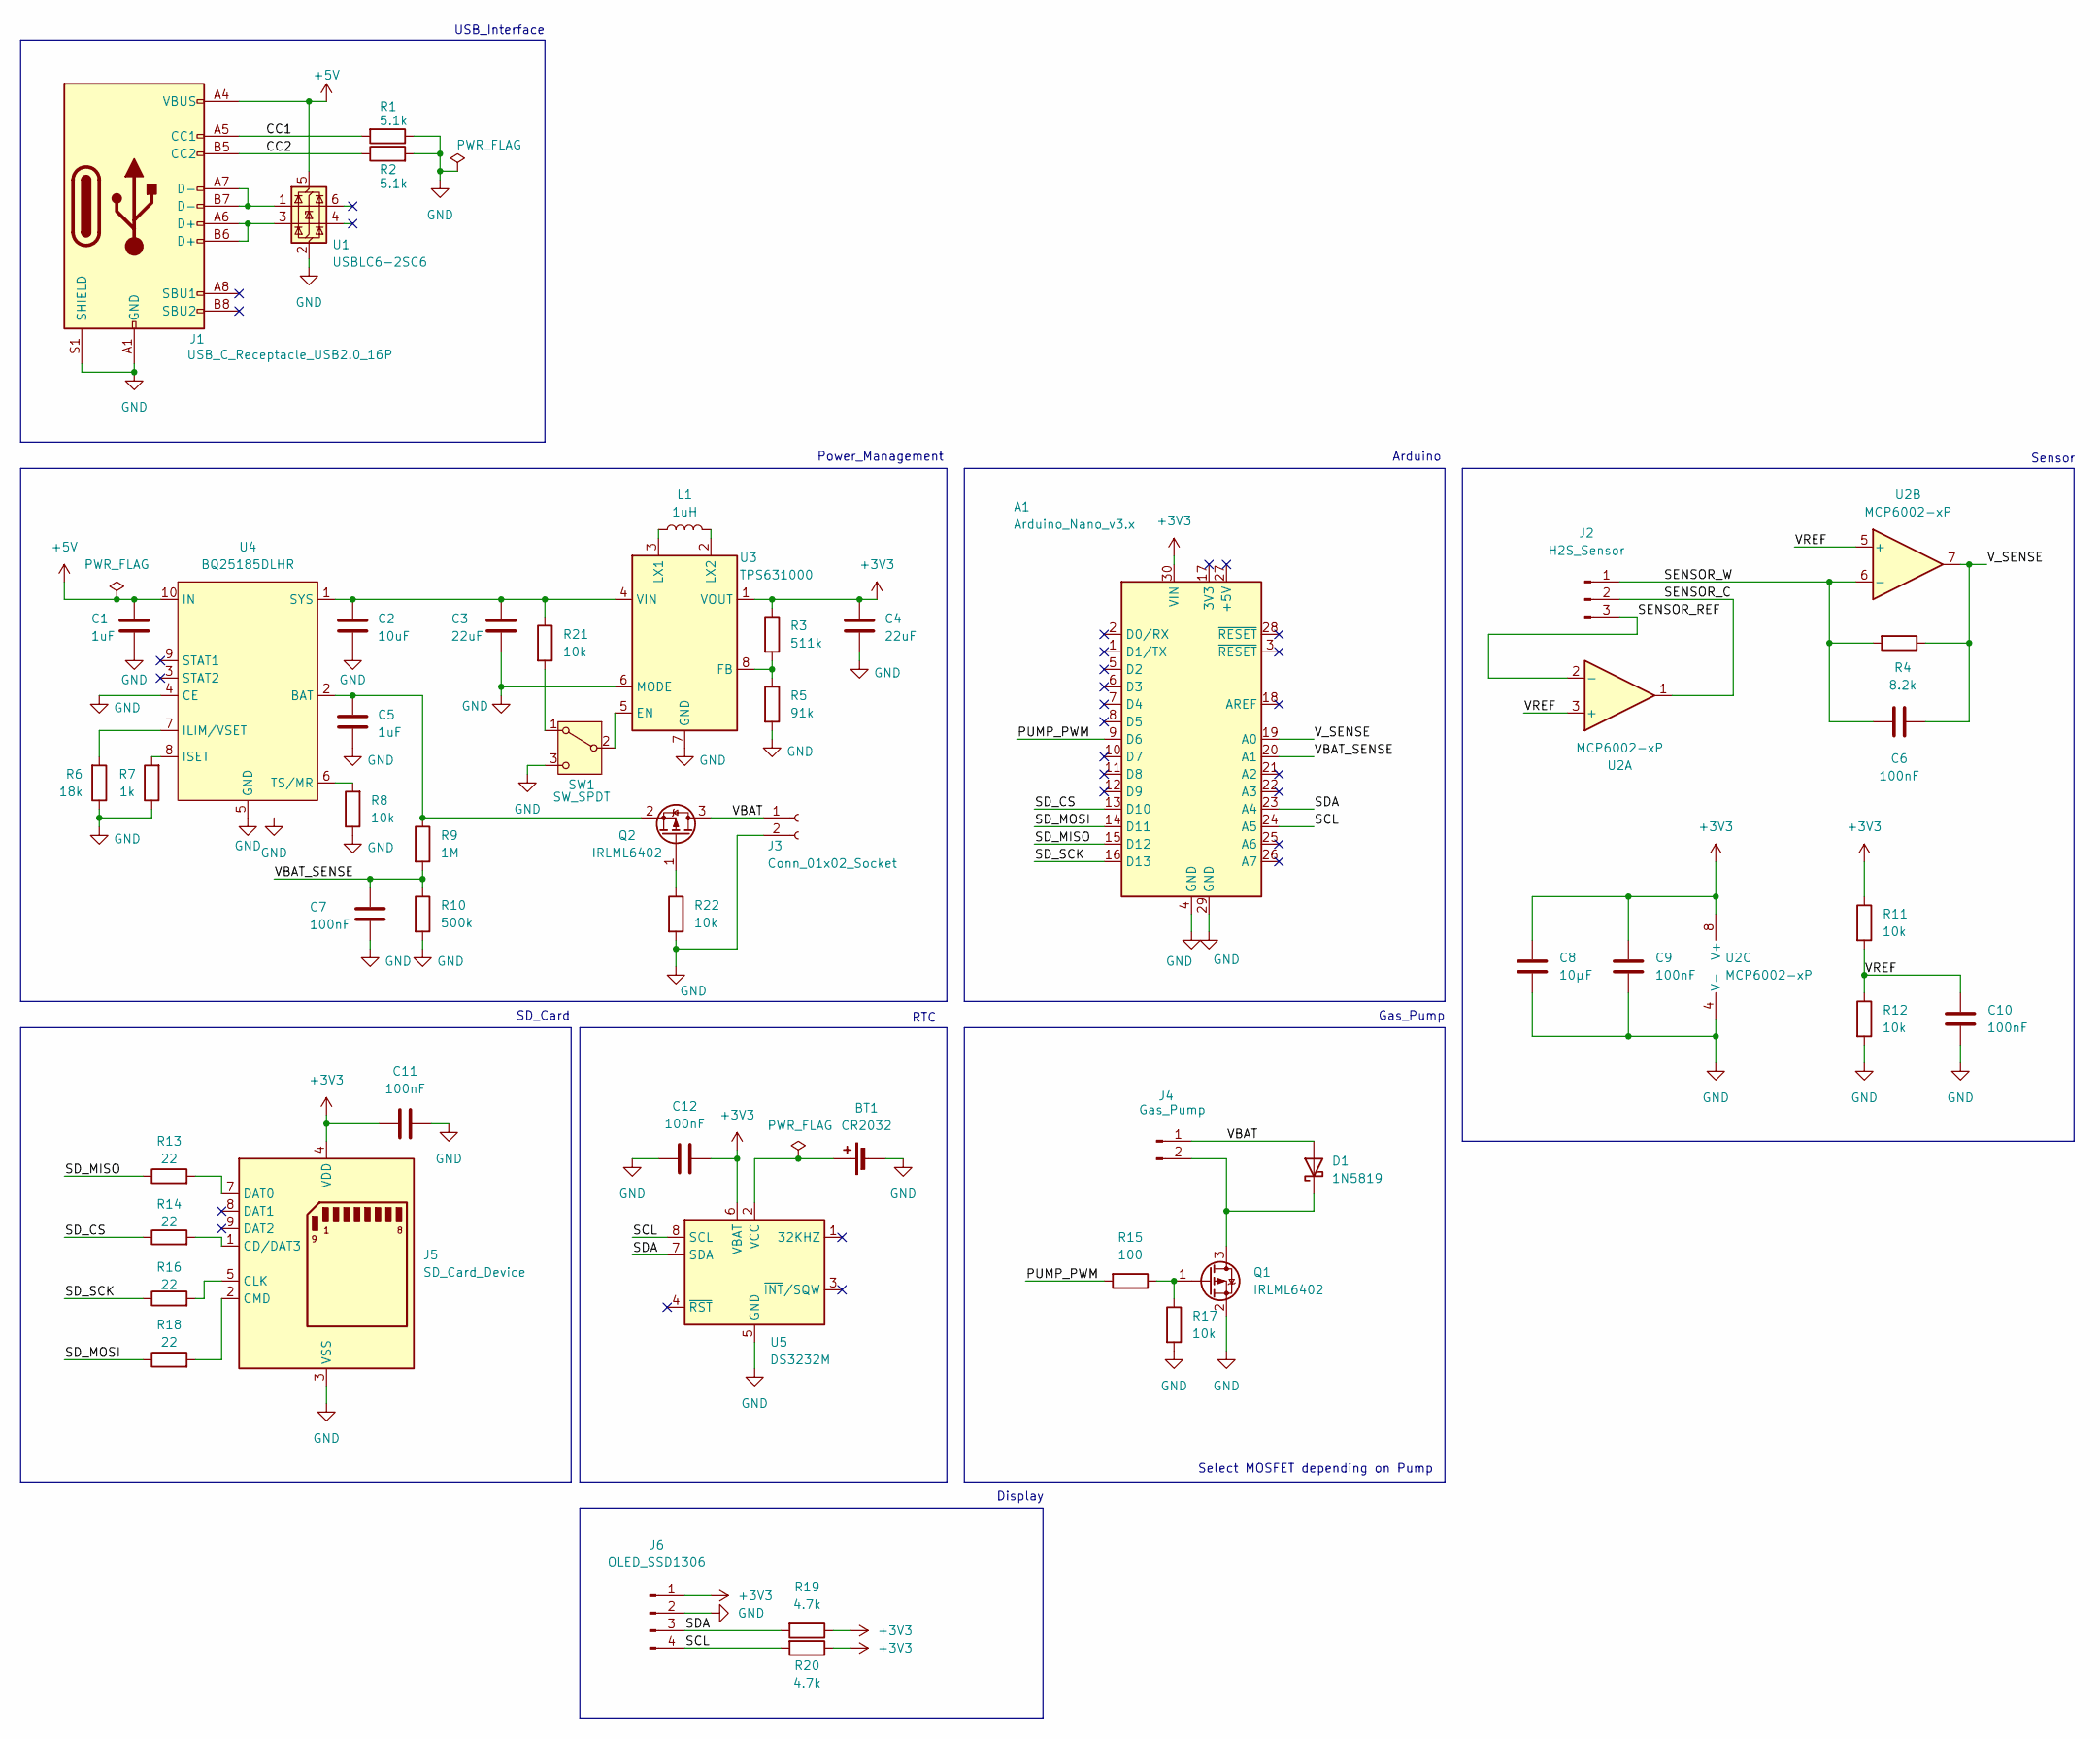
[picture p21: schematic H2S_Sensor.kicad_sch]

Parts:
A1: Arduino_Nano_v3.x; Arduino_Nano
BT1: CR2032; BAT-TH_CR2032-BS-6-1; LCSC Part C70377
C1, C5: 1uF; C_0603_1608Metric
C2: 10uF; C_0603_1608Metric
C3, C4: 22uF; C_0603_1608Metric
C6, C7, C9, C10, C11, C12: 100nF; C_0603_1608Metric
C8: 10µF; C_0603_1608Metric
D1: 1N5819; DO-41_BD2.4-L4.7-P8.70-D0.9-FD; LCSC Part C2474
J1: USB_C_Receptacle_USB2.0_16P; USB_C_Receptacle_GCT_USB4105-xx-A_16P_TopMnt_Horizontal
J2: H2S_Sensor; H2S_Sensor_3Pin_D20mm
J3: Conn_01x02_Socket; Hirose_DF13-02P-1.25DSA_1x02_P1.25mm_Vertical
J4: Gas_Pump; Hirose_DF13-02P-1.25DSA_1x02_P1.25mm_Vertical
J5: SD_Card_Device; SD-SMD_SD-006S-T; LCSC Part C125620
J6: OLED_SSD1306; Hirose_DF13-04P-1.25DSA_1x04_P1.25mm_Vertical
L1: 1uH; L_0805_2012Metric
Q1, Q2: IRLML6402; SOT-23
R1, R2: 5.1k; R_0603_1608Metric
R3: 511k; R_0603_1608Metric
R4: 8.2k; R_0603_1608Metric
R5: 91k; R_0603_1608Metric
R6: 18k; R_0603_1608Metric
R7: 1k; R_0603_1608Metric
R8, R11, R12, R17, R21, R22: 10k; R_0603_1608Metric
R9: 1M; R_0603_1608Metric
R10: 500k; R_0603_1608Metric
R13, R14, R16, R18: 22; R_0603_1608Metric
R15: 100; R_0603_1608Metric
R19, R20: 4.7k; R_0603_1608Metric
SW1: SW_SPDT; SW-SMD_MSK-03-HB; LCSC Part C54948
U1: USBLC6-2SC6; SOT-23-6_L2.9-W1.6-P0.95-LS2.8-BL; LCSC Part C7519
U2: MCP6002-xP; SOIC-8_3.9x4.9mm_P1.27mm
U3: TPS631000; SOT-583-8_L2.1-W1.2-P0.50-LS1.6-BL; LCSC Part C5219190
U4: BQ25185DLHR; WSON-10_L2.2-W2.0-P0.40-BL-EP_TI_DLH0010A; LCSC Part C19725033
U5: DS3232M; SOIC-8_3.9x4.9mm_P1.27mm

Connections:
+3V3: A1.30 (VIN), C4.2, C8.1, C9.1, C11.1, C12.2, J5.4 (VDD), J6.1, R3.1, R11.1, R19.1, R20.1, U2.8 (V+), U3.1 (VOUT), U5.6 (VBAT)
+5V: C1.2, J1.A4 (VBUS), J1.A9 (VBUS), J1.B4 (VBUS), J1.B9 (VBUS), U1.5 (VBUS), U4.10 (IN)
/CC1: J1.A5 (CC1), R1.2
/CC2: J1.B5 (CC2), R2.1
/PUMP_PWM: A1.9 (D6), R15.2
/SCL: A1.24 (A5), J6.4, R20.2, U5.8 (SCL)
/SDA: A1.23 (A4), J6.3, R19.2, U5.7 (SDA)
/SD_CS: A1.13 (D10), R14.1
/SD_MISO: A1.15 (D12), R13.1
/SD_MOSI: A1.14 (D11), R18.1
/SD_SCK: A1.16 (D13), R16.1
/SENSOR_C: J2.2, U2.1
/SENSOR_REF: J2.3, U2.2 (-)
/SENSOR_W: C6.1, J2.1, R4.2, U2.6 (-)
/VBAT: D1.2 (A), J3.1, J4.1, Q2.3 (D)
/VBAT_SENSE: A1.20 (A1), C7.1, R9.2, R10.1
/VREF: C10.1, R11.2, R12.1, U2.3 (+), U2.5 (+)
/V_SENSE: A1.19 (A0), C6.2, R4.1, U2.7
GND: A1.4 (GND), A1.29 (GND), BT1.2 (-), C1.1, C2.1, C3.1, C4.1, C5.1, C7.2, C8.2, C9.2, C10.2, C11.2, C12.1, J1.A1 (GND), J1.A12 (GND), J1.B1 (GND), J1.B12 (GND), J1.S1 (SHIELD), J3.2, J5.3 (VSS), J5.6 (VSS), J6.2, Q1.2 (S), R1.1, R2.2, R5.2, R6.1, R7.1, R8.1, R10.2, R12.2, R17.2, R22.2, SW1.3 (C), U1.2 (GND), U2.4 (V-), U3.6 (MODE), U3.7 (GND), U4.4 (CE), U4.5 (GND), U4.11 (VSS), U5.5 (GND)
unnamed: BT1.1 (+), U5.2 (VCC)
unnamed: D1.1 (K), J4.2, Q1.3 (D)
unnamed: J1.A6 (D+), J1.B6 (D+), U1.3 (I/O2)
unnamed: J1.A7 (D-), J1.B7 (D-), U1.1 (I/O1)
unnamed: J5.1 (CD/DAT3), R14.2
unnamed: J5.5 (CLK), R16.2
unnamed: J5.2 (CMD), R18.2
unnamed: J5.7 (DAT0), R13.2
unnamed: Q1.1 (G), R15.1, R17.1
unnamed: Q2.1 (G), R22.1
unnamed: C5.2, Q2.2 (S), R9.1, U4.2 (BAT)
unnamed: R21.2, SW1.1 (A)
unnamed: SW1.2 (B), U3.5 (EN)
unnamed: R3.2, R5.1, U3.8 (FB)
unnamed: L1.1, U3.3 (LX1)
unnamed: L1.2, U3.2 (LX2)
unnamed: C2.2, C3.2, R21.1, U3.4 (VIN), U4.1 (SYS)
unnamed: R6.2, U4.7 (ILIM/VSET)
unnamed: R7.2, U4.8 (ISET)
unnamed: R8.2, U4.6 (TS/MR)

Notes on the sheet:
Gas_Pump
Sensor
USB_Interface
Arduino
Display
RTC
Select MOSFET depending on Pump
SD_Card
Power_Management

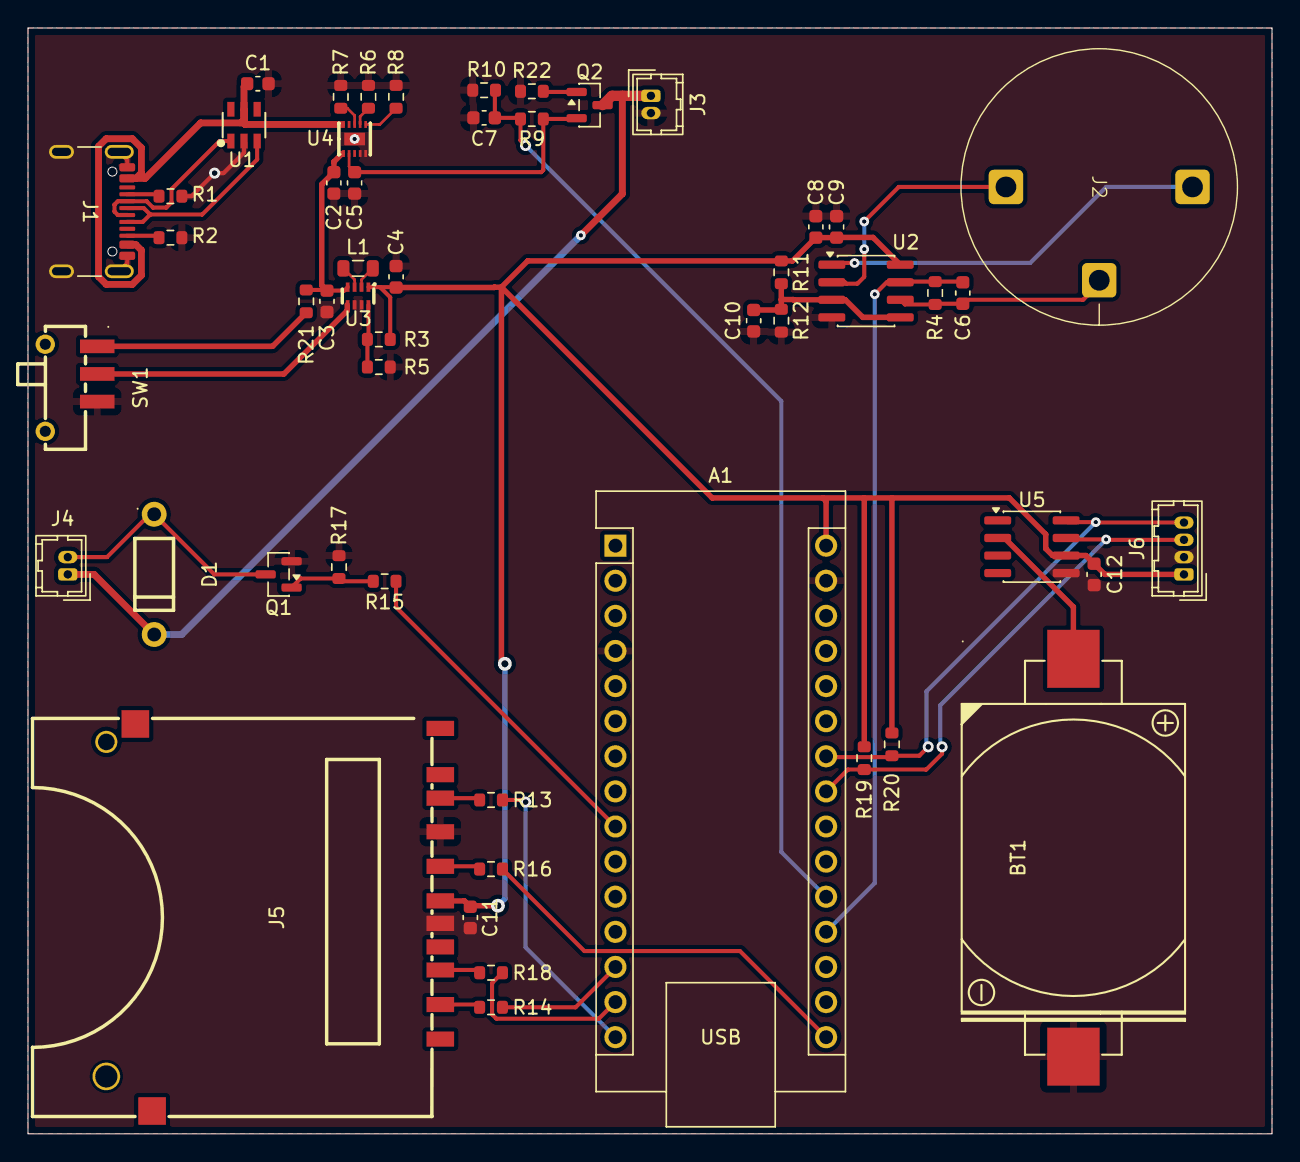
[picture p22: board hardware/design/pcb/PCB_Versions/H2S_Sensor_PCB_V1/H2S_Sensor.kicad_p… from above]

Board: 2 copper layers, 90.0 x 80.0 mm, 52 parts (0 on the bottom side), 39 nets.

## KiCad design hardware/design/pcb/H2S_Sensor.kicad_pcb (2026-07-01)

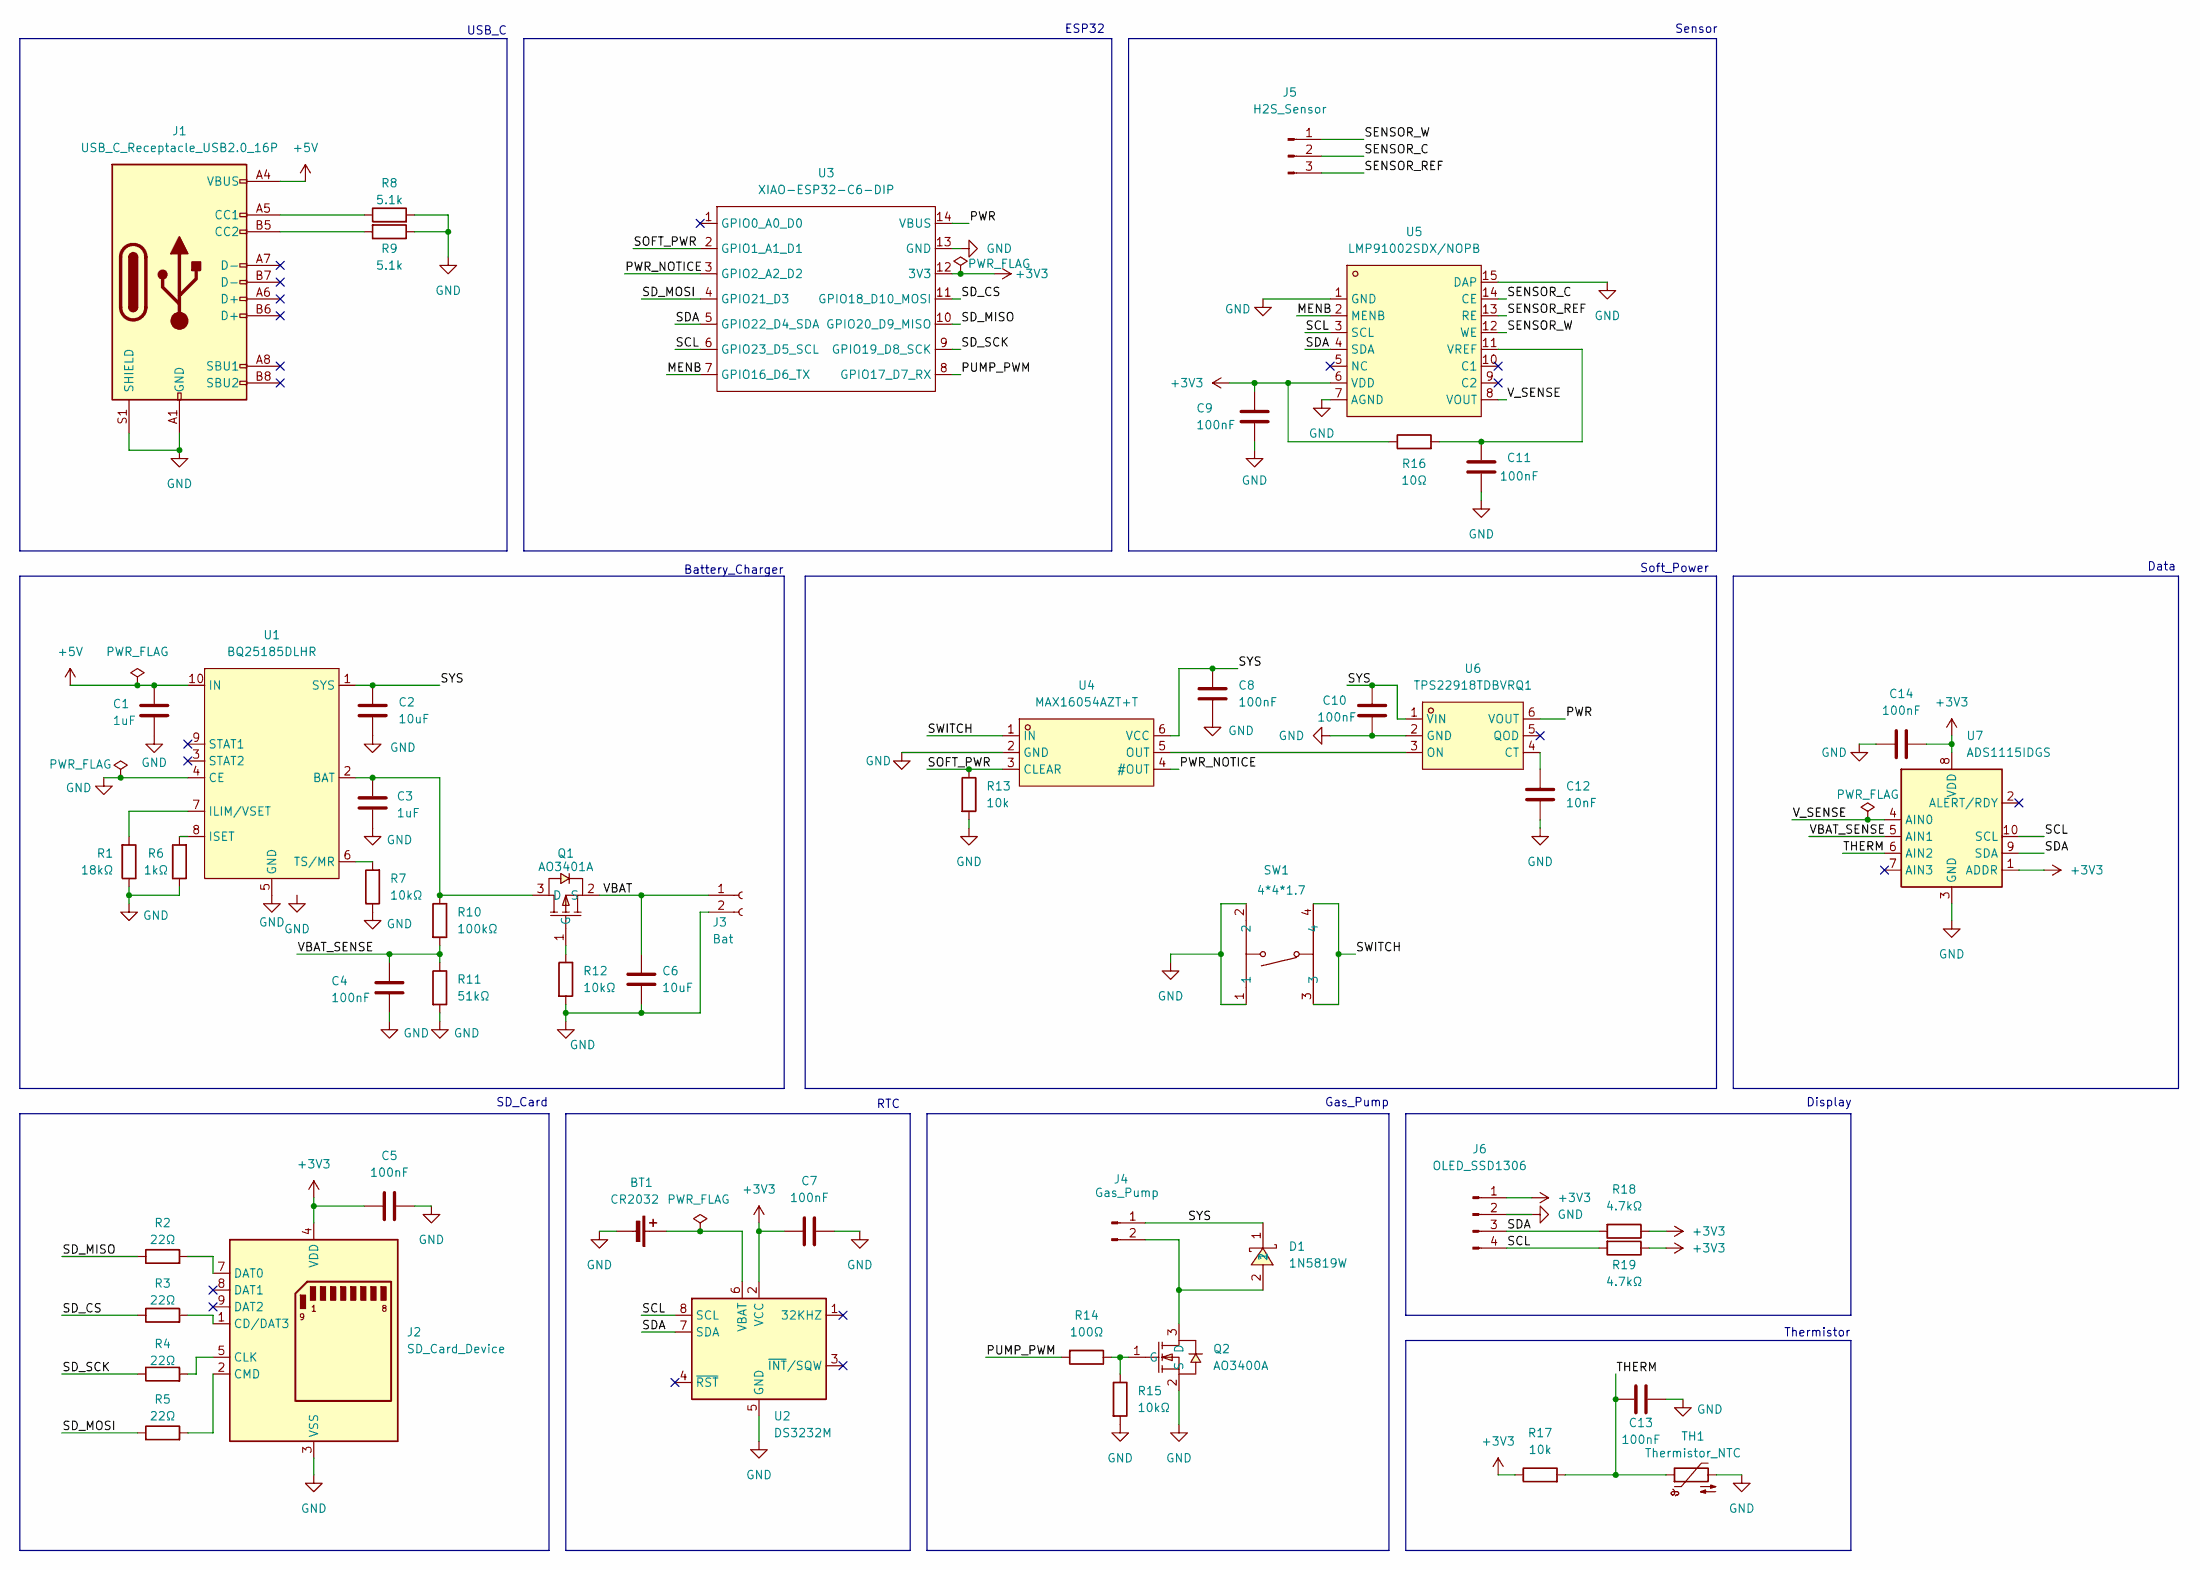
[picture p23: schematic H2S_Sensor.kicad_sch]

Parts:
BT1: CR2032; BAT-TH_CR2032-BS-6-1; LCSC Part C70377
C1, C3: 1uF; C_0603_1608Metric; LCSC Part C15849
C2, C6: 10uF; C_0603_1608Metric; LCSC Part C96446
C4, C5, C7, C8, C9, C10, C11, C13, C14: 100nF; C_0603_1608Metric; LCSC Part C14663
C12: 10nF; C_0603_1608Metric; LCSC Part C57112
D1: 1N5819W; SOD-123F_L2.8-W1.8-LS3.7-RD; MPN 1N5819W; LCSC Part C169540
J1: USB_C_Receptacle_USB2.0_16P; USB_C_Receptacle_GCT_USB4105-xx-A_16P_TopMnt_Horizontal; LCSC Part C2927037
J2: SD_Card_Device; TF-SMD_TF-15-15; LCSC Part C111196
J3: Bat; PinSocket_1x02_P2.54mm_Vertical
J4: Gas_Pump; PinSocket_1x02_P2.54mm_Vertical
J5: H2S_Sensor; H2S_Sensor_3Pin_D20mm
J6: OLED_SSD1306; PinSocket_1x04_P2.54mm_Vertical
Q1: AO3401A; SOT-23_L2.9-W1.3-P1.90-LS2.4-BR; MPN AO3401A; LCSC Part C15127
Q2: AO3400A; SOT-23-3_L2.9-W1.3-P1.90-LS2.4-BR; MPN AO3400A; LCSC Part C20917
R1: 18kΩ; R_0603_1608Metric; LCSC Part C25810
R2, R3, R4, R5: 22Ω; R_0603_1608Metric; LCSC Part C23345
R6: 1kΩ; R_0603_1608Metric; LCSC Part C21190
R7, R12, R15: 10kΩ; R_0603_1608Metric; LCSC Part C25804
R8, R9: 5.1k; R_0603_1608Metric; LCSC Part C23186
R10: 100kΩ; R_0603_1608Metric; LCSC Part C22935
R11: 51kΩ; R_0603_1608Metric; LCSC Part C23192
R13, R17: 10k; R_0603_1608Metric; LCSC Part C25804
R14: 100Ω; R_0603_1608Metric; LCSC Part C22775
R16: 10Ω; R_0603_1608Metric; LCSC Part C22859
R18, R19: 4.7kΩ; R_0603_1608Metric; LCSC Part C23162
SW1: 4*4*1.7; SW-SMD_4P-L5.2-W5.2-P3.70-LS6.5; MPN 4*4*1.7 贴片; LCSC Part C10852
TH1: Thermistor_NTC; R_0603_1608Metric; LCSC Part C7462093
U1: BQ25185DLHR; WSON-10_L2.2-W2.0-P0.40-BL-EP_TI_DLH0010A; LCSC C19725033
U2: DS3232M; SOIC-8_3.9x4.9mm_P1.27mm; LCSC Part C2827535
U3: XIAO-ESP32-C6-DIP
U4: MAX16054AZT+T; TSOT-23-6_L2.9-W1.6-P0.95-LS2.8-TL; MPN MAX16054AZT+T; LCSC Part C79401
U5: LMP91002SDX/NOPB; WSON-14_L4.0-W4.0-P0.50-BL-EP; MPN LMP91002SDX/NOPB; LCSC Part C2651581
U6: TPS22918TDBVRQ1; SOT-23-6_L2.9-W1.6-P0.95-LS2.8-BR; MPN TPS22918TDBVRQ1; LCSC Part C2653760
U7: ADS1115IDGS; TSSOP-10_3x3mm_P0.5mm; LCSC Part C468683

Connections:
+3V3: C5.1, C7.2, C9.1, C14.2, J2.4 (VDD), J6.1, R16.1, R17.1, R18.1, R19.1, U2.2 (VCC), U3.12 (3V3), U5.6 (VDD), U7.1 (ADDR), U7.8 (VDD)
+5V: C1.2, J1.A4 (VBUS), J1.A9 (VBUS), J1.B4 (VBUS), J1.B9 (VBUS), U1.10 (IN)
/MENB: U3.7 (GPIO16_D6_TX), U5.2 (MENB)
/PUMP_PWM: R14.2, U3.8 (GPIO17_D7_RX)
/PWR: U3.14 (VBUS), U6.6 (VOUT)
/PWR_NOTICE: U3.3 (GPIO2_A2_D2), U4.4 (#OUT)
/SCL: J6.4, R19.2, U2.8 (SCL), U3.6 (GPIO23_D5_SCL), U5.3 (SCL), U7.10 (SCL)
/SDA: J6.3, R18.2, U2.7 (SDA), U3.5 (GPIO22_D4_SDA), U5.4 (SDA), U7.9 (SDA)
/SD_CS: R3.1, U3.11 (GPIO18_D10_MOSI)
/SD_MISO: R2.1, U3.10 (GPIO20_D9_MISO)
/SD_MOSI: R5.1, U3.4 (GPIO21_D3)
/SD_SCK: R4.1, U3.9 (GPIO19_D8_SCK)
/SENSOR_C: J5.2, U5.14 (CE)
/SENSOR_REF: J5.3, U5.13 (RE)
/SENSOR_W: J5.1, U5.12 (WE)
/SOFT_PWR: R13.1, U3.2 (GPIO1_A1_D1), U4.3 (CLEAR)
/SWITCH: SW1.3, SW1.4, U4.1 (IN)
/SYS: C2.1, C8.1, C10.1, D1.1, J4.1, U1.1 (SYS), U4.6 (VCC), U6.1 (VIN)
/THERM: C13.2, R17.2, TH1.1, U7.6 (AIN2)
/VBAT: C6.2, J3.1, Q1.2 (S)
/VBAT_SENSE: C4.1, R10.2, R11.1, U7.5 (AIN1)
/V_SENSE: U5.8 (VOUT), U7.4 (AIN0)
GND: BT1.2 (-), C1.1, C2.2, C3.1, C4.2, C5.2, C6.1, C7.1, C8.2, C9.2, C10.2, C11.2, C12.2, C13.1, C14.1, J1.A1 (GND), J1.A12 (GND), J1.B1 (GND), J1.B12 (GND), J1.S1 (SHIELD), J2.3 (VSS), J2.6 (VSS), J3.2, J6.2, Q2.2 (S), R1.1, R6.1, R7.1, R8.2, R9.1, R11.2, R12.2, R13.2, R15.2, SW1.1, SW1.2, TH1.2, U1.4 (CE), U1.5 (GND), U1.11 (VSS), U2.5 (GND), U3.13 (GND), U4.2 (GND), U5.1 (GND), U5.7 (AGND), U5.15 (DAP), U6.2 (GND), U7.3 (GND)
unnamed: BT1.1 (+), U2.6 (VBAT)
unnamed: J1.A5 (CC1), R8.1
unnamed: J1.B5 (CC2), R9.2
unnamed: J2.1 (CD/DAT3), R3.2
unnamed: J2.5 (CLK), R4.2
unnamed: J2.2 (CMD), R5.2
unnamed: J2.7 (DAT0), R2.2
unnamed: D1.2, J4.2, Q2.3 (D)
unnamed: C3.2, Q1.3 (D), R10.1, U1.2 (BAT)
unnamed: Q1.1 (G), R12.1
unnamed: Q2.1 (G), R14.1, R15.1
unnamed: R1.2, U1.7 (ILIM/VSET)
unnamed: R6.2, U1.8 (ISET)
unnamed: R7.2, U1.6 (TS/MR)
unnamed: U4.5 (OUT), U6.3 (ON)
unnamed: C11.1, R16.2, U5.11 (VREF)
unnamed: C12.1, U6.4 (CT)

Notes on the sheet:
Gas_Pump
Sensor
Thermistor
ESP32
Display
RTC
Data
Soft_Power
SD_Card
USB_C
Battery_Charger

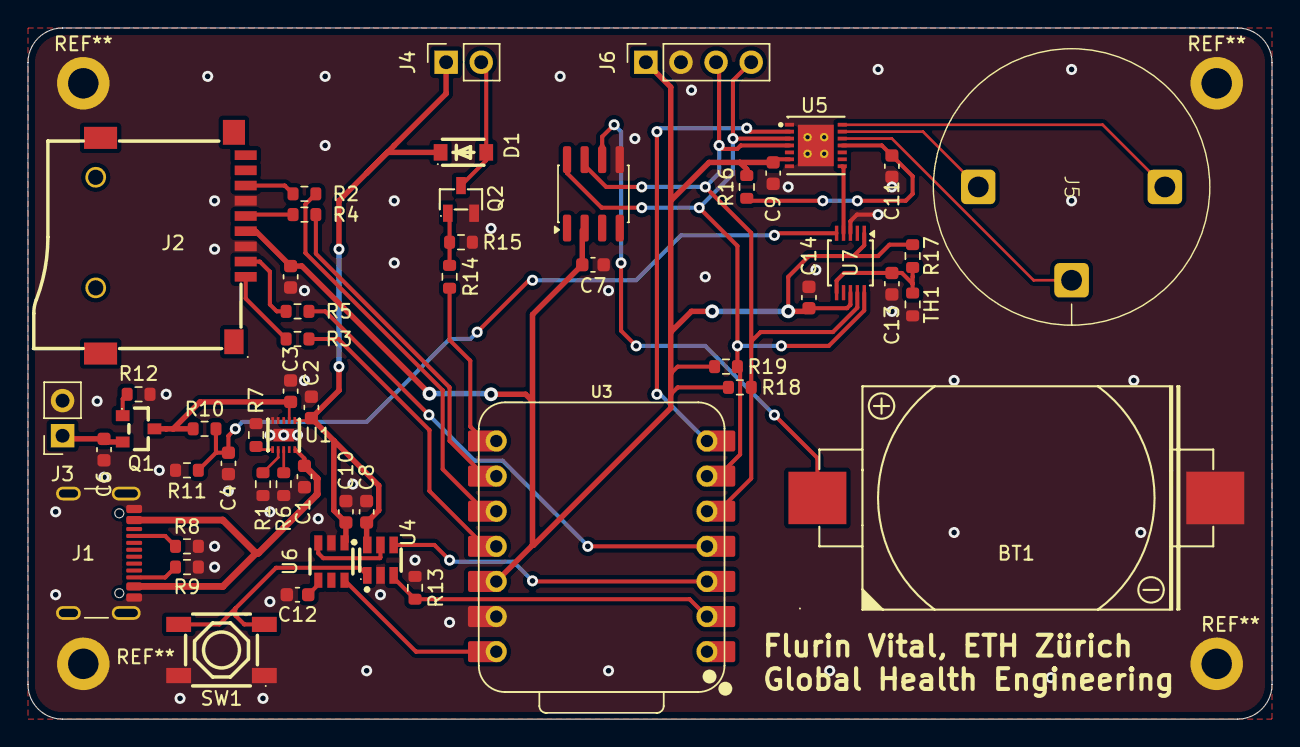
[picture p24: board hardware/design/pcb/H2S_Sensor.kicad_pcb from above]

Board: 2 copper layers, 90.0 x 50.0 mm, 52 parts (0 on the bottom side), 40 nets.

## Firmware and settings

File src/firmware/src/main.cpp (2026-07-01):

#include "display.h"
#include "sensor.h"
#include "storage.h"
#include "pump.h"
#include "power.h"
#include "rtc.h"
#include "sample.h"
#include "app_config.h"
#include "queues.h"
#include "freertos/FreeRTOS.h"
#include "freertos/task.h"
#include "freertos/semphr.h"
#include "esp_log.h"
#include "driver/gpio.h"
#include "nvs_flash.h"
#include <stdio.h>

static const char *TAG = "main";

static void pump_delayed_start(void *pv) {
    vTaskDelay(pdMS_TO_TICKS(10000));
    pump_run_continuous();
    vTaskDelete(NULL);
}

// FreeRTOS queues
QueueHandle_t q_display = NULL;
QueueHandle_t q_storage = NULL;
SemaphoreHandle_t i2c_mutex = NULL;
SemaphoreHandle_t sd_mutex = NULL;

static void app_fatal(const char *message) {
	ESP_LOGE(TAG, "FATAL: %s", message ? message : "unknown");
	for (;;) {
		vTaskDelay(pdMS_TO_TICKS(1000));
	}
}

extern "C" void app_main(void) {
	ESP_LOGI(TAG, "app_main started");

	// NVS must be initialised before any driver that reads persistent config.
	esp_err_t nvs_ret = nvs_flash_init();
	if (nvs_ret == ESP_ERR_NVS_NO_FREE_PAGES || nvs_ret == ESP_ERR_NVS_NEW_VERSION_FOUND) {
		ESP_ERROR_CHECK(nvs_flash_erase());
		nvs_ret = nvs_flash_init();
	}
	ESP_ERROR_CHECK(nvs_ret);

	// Mutexes and queues must exist before any init that touches I2C or SD.
	q_display = xQueueCreate(APP_DISPLAY_QUEUE_LENGTH, sizeof(sample_t));
	q_storage = xQueueCreate(APP_STORAGE_QUEUE_LENGTH, sizeof(sample_t));
	i2c_mutex = xSemaphoreCreateMutex();
	sd_mutex  = xSemaphoreCreateMutex();
	if (!q_display || !q_storage || !i2c_mutex || !sd_mutex) {
		app_fatal("failed to create queues or mutexes");
	}
	ESP_LOGI(TAG, "queues and mutexes OK");

	// sensor_init installs the I2C driver; display_init must come after.
	ESP_LOGI(TAG, "sensor_init...");
	sensor_init();
	ESP_LOGI(TAG, "rtc_init...");
	rtc_init();
	ESP_LOGI(TAG, "display_init...");
	display_init();
	ESP_LOGI(TAG, "storage_init...");
	storage_init();
	ESP_LOGI(TAG, "pump_init...");
	pump_init();
	ESP_LOGI(TAG, "power_init...");
	power_init();

	ESP_LOGI(TAG, "all init done, starting tasks");

	// Create tasks
	xTaskCreate(sensor_task,         "SensorTask",  APP_SENSOR_TASK_STACK,  NULL, APP_SENSOR_TASK_PRIO,  NULL);
	xTaskCreate(display_task,        "DisplayTask", APP_DISPLAY_TASK_STACK, NULL, APP_DISPLAY_TASK_PRIO, NULL);
	xTaskCreate(storage_task,        "StorageTask", APP_STORAGE_TASK_STACK, NULL, APP_STORAGE_TASK_PRIO, NULL);
	xTaskCreate(power_task,          "PowerTask",   APP_POWER_TASK_STACK,   NULL, APP_POWER_TASK_PRIO,   NULL);
	xTaskCreate(pump_delayed_start,  "PumpStart",   1024,                   NULL, 1,                     NULL);

	// Keep main alive (tasks run in FreeRTOS)
	for (;;) {
		vTaskDelay(pdMS_TO_TICKS(10000));
	}
}

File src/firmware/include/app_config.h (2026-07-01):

#ifndef APP_CONFIG_H
#define APP_CONFIG_H

#define APP_SENSOR_PERIOD_MS    3000
#define APP_DISPLAY_REFRESH_MS  1000
#define APP_POWER_MONITOR_MS    10000

#define APP_DISPLAY_QUEUE_LENGTH 8
#define APP_STORAGE_QUEUE_LENGTH 32

#define APP_DISPLAY_TASK_STACK  4096
#define APP_SENSOR_TASK_STACK   4096
#define APP_STORAGE_TASK_STACK  8192
#define APP_POWER_TASK_STACK    4096

#define APP_DISPLAY_TASK_PRIO   1
#define APP_SENSOR_TASK_PRIO    2
#define APP_STORAGE_TASK_PRIO   1
#define APP_POWER_TASK_PRIO     3

#define APP_LOW_BATTERY_MV      3200  // ~17% for Li-Ion (3.0V cutoff, 4.2V full)
#define APP_PUMP_DEFAULT_MS     2000
#define APP_OLED_I2C_ADDR       0x3C

// LMP91002 TIA feedback resistor (Ohms) — adjust after PCB testing
#define SENSOR_TIA_GAIN_OHMS    35000

// Samples before zero-calibration starts (at APP_SENSOR_PERIOD_MS each).
// Electrochemical sensors need ~60 s to stabilise — 20 × 3 s = 60 s.
#define SENSOR_WARMUP_SAMPLES   20

// Samples averaged to compute the zero-reference voltage.
// More samples → more stable baseline estimate.
#define SENSOR_CAL_SAMPLES      30

// ADS1115 supply voltage (used for Vref calculation)
#define ADS1115_VDD             3.3f

#endif // APP_CONFIG_H

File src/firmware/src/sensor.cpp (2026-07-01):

#include "sensor.h"
#include "app_config.h"
#include "calibration.h"
#include "sample.h"
#include "queues.h"
#include "power.h"
#include "rtc.h"
#include "freertos/FreeRTOS.h"
#include "freertos/task.h"
#include "driver/i2c.h"  // TODO: migrate to driver/i2c_master.h before ESP-IDF v7.0
#include "driver/gpio.h"
#include "esp_log.h"
#include <math.h>
#include <stdint.h>
#include <string.h>
#include "nvs_flash.h"
#include "nvs.h"

static const char *TAG = "sensor";

// Voltage measured at AIN0 in clean air — used as the zero reference for ppm.
// Loaded from NVS on boot; updated at the end of every calibration sequence.
static float g_v_zero = 3.3f * 0.20f;  // safe default until first calibration

static void nvs_load_v_zero(void) {
    nvs_handle_t h;
    if (nvs_open("sensor_cal", NVS_READONLY, &h) != ESP_OK) return;
    uint32_t raw = 0;
    if (nvs_get_u32(h, "v_zero", &raw) == ESP_OK) {
        memcpy(&g_v_zero, &raw, sizeof(float));
        ESP_LOGI(TAG, "NVS v_zero loaded: %.4fV", g_v_zero);
    }
    nvs_close(h);
}

static void nvs_save_v_zero(float v) {
    nvs_handle_t h;
    if (nvs_open("sensor_cal", NVS_READWRITE, &h) != ESP_OK) return;
    uint32_t raw;
    memcpy(&raw, &v, sizeof(float));
    nvs_set_u32(h, "v_zero", raw);
    nvs_commit(h);
    nvs_close(h);
    ESP_LOGI(TAG, "NVS v_zero saved: %.4fV", v);
}

// ── I2C bus ──────────────────────────────────────────────────────────────────
#define I2C_PORT     I2C_NUM_0
#define I2C_SDA      GPIO_NUM_22
#define I2C_SCL      GPIO_NUM_23
#define I2C_FREQ_HZ  100000
#define ACK_EN       true

// ── LMP91002 ─────────────────────────────────────────────────────────────────
#define LMP_MENB_GPIO  GPIO_NUM_16   // active-low enable; shared with UART0 TX
#define LMP_ADDR       0x48
#define LMP_REG_LOCK   0x01
#define LMP_REG_TIACN  0x10
#define LMP_REG_REFCN  0x11
#define LMP_REG_MODECN 0x12

// TIACN: TIA gain 35 kΩ = bits [4:2] = 0b101
#define LMP_TIACN_RLOAD_10 0x00   // RLOAD = 10 Ω (bits [1:0])
#define LMP_GAIN_35K       (5 << 2)
// REFCN: INT_Z=20% → INTZCAL bits[6:5]=00, BIAS=0, internal ref → value 0x00
#define LMP_REFCN_INT_20   0x00
// MODECN: 3-lead amperometric
#define LMP_MODE_3LEAD     0x03

static esp_err_t lmp_read_reg(uint8_t reg, uint8_t *val) {
    i2c_cmd_handle_t cmd = i2c_cmd_link_create();
    i2c_master_start(cmd);
    i2c_master_write_byte(cmd, (LMP_ADDR << 1) | I2C_MASTER_WRITE, ACK_EN);
    i2c_master_write_byte(cmd, reg, ACK_EN);
    i2c_master_stop(cmd);
    esp_err_t ret = i2c_master_cmd_begin(I2C_PORT, cmd, pdMS_TO_TICKS(100));
    i2c_cmd_link_delete(cmd);
    if (ret != ESP_OK) return ret;

    cmd = i2c_cmd_link_create();
    i2c_master_start(cmd);
    i2c_master_write_byte(cmd, (LMP_ADDR << 1) | I2C_MASTER_READ, ACK_EN);
    i2c_master_read_byte(cmd, val, I2C_MASTER_LAST_NACK);
    i2c_master_stop(cmd);
    ret = i2c_master_cmd_begin(I2C_PORT, cmd, pdMS_TO_TICKS(100));
    i2c_cmd_link_delete(cmd);
    return ret;
}

static esp_err_t lmp_write_reg(uint8_t reg, uint8_t val) {
    uint8_t buf[2] = {reg, val};
    i2c_cmd_handle_t cmd = i2c_cmd_link_create();
    i2c_master_start(cmd);
    i2c_master_write_byte(cmd, (LMP_ADDR << 1) | I2C_MASTER_WRITE, ACK_EN);
    i2c_master_write(cmd, buf, 2, ACK_EN);
    i2c_master_stop(cmd);
    esp_err_t ret = i2c_master_cmd_begin(I2C_PORT, cmd, pdMS_TO_TICKS(100));
    i2c_cmd_link_delete(cmd);
    return ret;
}

static esp_err_t lmp_init(void) {
    // Unlock registers
    esp_err_t r = lmp_write_reg(LMP_REG_LOCK, 0x00);
    if (r != ESP_OK) return r;

    r = lmp_write_reg(LMP_REG_TIACN, LMP_GAIN_35K | LMP_TIACN_RLOAD_10);
    if (r != ESP_OK) return r;

    r = lmp_write_reg(LMP_REG_REFCN, LMP_REFCN_INT_20);
    if (r != ESP_OK) return r;

    r = lmp_write_reg(LMP_REG_MODECN, LMP_MODE_3LEAD);
    return r;
}

// ── ADS1115 ──────────────────────────────────────────────────────────────────
#define ADS_ADDR     0x49
#define ADS_REG_CONV   0x00
#define ADS_REG_CFG    0x01

// Config register high byte: OS=1(start), MUX=AIN0..3 vs GND, PGA, MODE=single
#define ADS_OS_START   0x80
#define ADS_MUX_AIN0   0x40   // 100 → AIN0/GND
#define ADS_MUX_AIN1   0x50   // 101 → AIN1/GND
#define ADS_MUX_AIN2   0x60   // 110 → AIN2/GND
#define ADS_PGA_2V048  0x04   // bits[3:1] = 010 → ±2.048 V, 62.5 µV/LSB
#define ADS_PGA_4V096  0x02   // bits[3:1] = 001 → ±4.096 V, 125 µV/LSB
#define ADS_MODE_SINGLE 0x01  // bit0 of high byte
// Config register low byte: 128 SPS (bits[7:5]=100), comparator disabled
#define ADS_DR_128SPS  0x80
#define ADS_COMP_OFF   0x03

static esp_err_t ads_write_reg(uint8_t reg, uint16_t val) {
    uint8_t buf[3] = {reg, (uint8_t)(val >> 8), (uint8_t)(val & 0xFF)};
    i2c_cmd_handle_t cmd = i2c_cmd_link_create();
    i2c_master_start(cmd);
    i2c_master_write_byte(cmd, (ADS_ADDR << 1) | I2C_MASTER_WRITE, ACK_EN);
    i2c_master_write(cmd, buf, 3, ACK_EN);
    i2c_master_stop(cmd);
    esp_err_t ret = i2c_master_cmd_begin(I2C_PORT, cmd, pdMS_TO_TICKS(100));
    i2c_cmd_link_delete(cmd);
    return ret;
}

static esp_err_t ads_read_reg(uint8_t reg, uint16_t *out) {
    // Set pointer
    i2c_cmd_handle_t cmd = i2c_cmd_link_create();
    i2c_master_start(cmd);
    i2c_master_write_byte(cmd, (ADS_ADDR << 1) | I2C_MASTER_WRITE, ACK_EN);
    i2c_master_write_byte(cmd, reg, ACK_EN);
    i2c_master_stop(cmd);
    esp_err_t ret = i2c_master_cmd_begin(I2C_PORT, cmd, pdMS_TO_TICKS(100));
    i2c_cmd_link_delete(cmd);
    if (ret != ESP_OK) return ret;

    // Read 2 bytes
    uint8_t buf[2];
    cmd = i2c_cmd_link_create();
    i2c_master_start(cmd);
    i2c_master_write_byte(cmd, (ADS_ADDR << 1) | I2C_MASTER_READ, ACK_EN);
    i2c_master_read(cmd, buf, 2, I2C_MASTER_LAST_NACK);
    i2c_master_stop(cmd);
    ret = i2c_master_cmd_begin(I2C_PORT, cmd, pdMS_TO_TICKS(100));
    i2c_cmd_link_delete(cmd);
    if (ret == ESP_OK) {
        *out = ((uint16_t)buf[0] << 8) | buf[1];
    }
    return ret;
}

// Trigger single-shot conversion on given mux and PGA, return voltage in Volts.
// Caller must hold i2c_mutex.
static float ads_read_voltage(uint8_t mux_hi, uint8_t pga_hi) {
    uint16_t cfg = ((uint16_t)(ADS_OS_START | mux_hi | pga_hi | ADS_MODE_SINGLE) << 8)
                 | ((uint16_t)(ADS_DR_128SPS | ADS_COMP_OFF));
    if (ads_write_reg(ADS_REG_CFG, cfg) != ESP_OK) return 0.0f;

    // Wait for conversion (~8 ms @ 128 SPS; poll OS bit)
    for (int i = 0; i < 20; i++) {
        vTaskDelay(pdMS_TO_TICKS(10));
        uint16_t status;
        if (ads_read_reg(ADS_REG_CFG, &status) == ESP_OK) {
            if (status & 0x8000) break;  // OS=1 → conversion done
        }
    }

    uint16_t raw;
    if (ads_read_reg(ADS_REG_CONV, &raw) != ESP_OK) return 0.0f;

    int16_t signed_raw = (int16_t)raw;
    float lsb = (pga_hi == ADS_PGA_4V096) ? 125e-6f : 62.5e-6f;
    return (float)signed_raw * lsb;
}

// ── Public API ────────────────────────────────────────────────────────────────
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

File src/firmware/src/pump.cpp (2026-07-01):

#include "pump.h"
#include "sample.h"
#include "app_config.h"
#include "freertos/FreeRTOS.h"
#include "freertos/task.h"
#include "freertos/timers.h"
#include "driver/gpio.h"
#include "esp_log.h"
#include <stddef.h>

static const char *TAG = "pump";

#define PUMP_GPIO GPIO_NUM_17

static TimerHandle_t s_pump_timer = NULL;

static void pump_timer_cb(TimerHandle_t xTimer) {
    (void)xTimer;
    gpio_set_level(PUMP_GPIO, 0);
    ESP_LOGI(TAG, "pump OFF (timer expired)");
}

void pump_init(void) {
    gpio_config_t cfg = {
        .pin_bit_mask = (1ULL << PUMP_GPIO),
        .mode         = GPIO_MODE_OUTPUT,
        .pull_up_en   = GPIO_PULLUP_DISABLE,
        .pull_down_en = GPIO_PULLDOWN_DISABLE,
        .intr_type    = GPIO_INTR_DISABLE,
    };
    gpio_config(&cfg);
    gpio_set_level(PUMP_GPIO, 0);

    s_pump_timer = xTimerCreate("pump", pdMS_TO_TICKS(APP_PUMP_DEFAULT_MS),
                                pdFALSE, NULL, pump_timer_cb);
}

void pump_start(uint32_t duration_ms) {
    if (!s_pump_timer) return;
    ESP_LOGI(TAG, "pump ON for %lu ms", (unsigned long)duration_ms);
    gpio_set_level(PUMP_GPIO, 1);
    xTimerChangePeriod(s_pump_timer, pdMS_TO_TICKS(duration_ms), 0);
    xTimerStart(s_pump_timer, 0);
}

void pump_run_continuous(void) {
    if (s_pump_timer) xTimerStop(s_pump_timer, 0);
    gpio_set_level(PUMP_GPIO, 1);
    ESP_LOGI(TAG, "pump ON (continuous)");
}

void pump_stop(void) {
    if (s_pump_timer) xTimerStop(s_pump_timer, 0);
    gpio_set_level(PUMP_GPIO, 0);
    ESP_LOGI(TAG, "pump OFF (manual stop)");
}

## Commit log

2026-04-27 add pcb v2
    [H2S_Sensor.kicad_pcb, H2S_Sensor.kicad_sch]
2026-04-27 sensor documentation
2026-04-27 v2 pcb review comments
2026-05-28 Remove all files
    [H2S_Sensor.kicad_pcb, H2S_Sensor.kicad_sch]
2026-05-28 Add H2S sensor PCB design files as pcb_design
    [H2S_Sensor.kicad_pcb, H2S_Sensor.kicad_sch, H2S_V5_bom.csv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]
2026-05-28 Remove invoice.pdf from pcb_design
2026-06-04 Move pcb_design into hardware/design/pcb
    [H2S_Sensor.kicad_pcb, H2S_Sensor.kicad_sch, H2S_V5_bom.csv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]
2026-06-04 Add CAD design files to hardware/design/case_CAD
    [Case_Bottom - Part 1.stl, Case_Top - Part 1.stl, Flow_Chamber - Part 1_V1.stl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]
2026-06-04 Add XIAO firmware to src and raw sensor data to data/raw_data
    [h2s_20260601_115100.csv]
2026-06-04 Move CSV to raw_data/baseline_stability and rename XIAO_firmware to firmware
    [h2s_20260601_115100.csv]
2026-06-04 Add proposal documents to docs/proposal
    [Gantt_Chart.xlsx]
2026-06-04 Move proposal files from docs/proposal to docs/reports
    [Gantt_Chart.xlsx]
2026-06-04 Add PCB photos to media/photo
2026-06-04 Add schematic PDF and device photos to media/photo
2026-06-04 Update tree.txt with current repo structure
